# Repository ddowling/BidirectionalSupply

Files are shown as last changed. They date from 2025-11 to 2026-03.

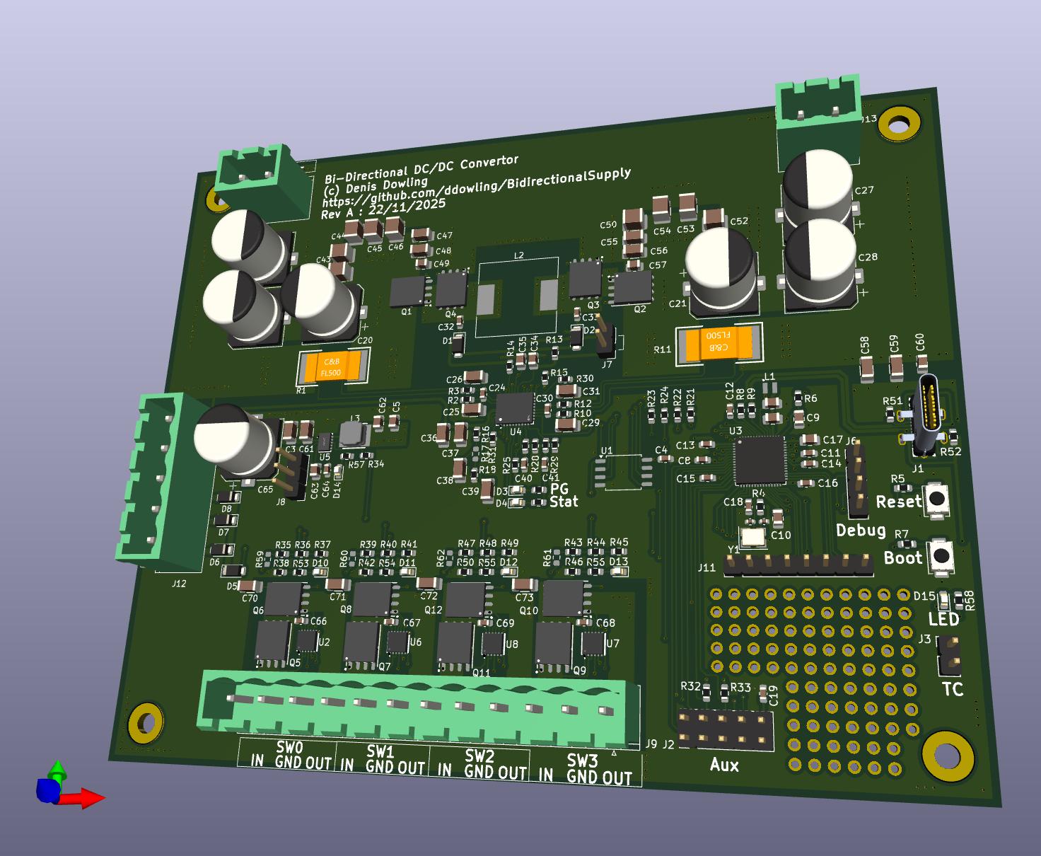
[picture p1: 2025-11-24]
doc/PCB3D.jpg

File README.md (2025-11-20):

This is a design for a Bidirectional Buck-Boost DC-DC converter based on the Texas Instruments [BQ25758](https://www.ti.com/lit/ds/symlink/bq25758.pdf) integrated circuit. 
The BQ25758 has a wide supply range from 4.2V to 60V and the external MOSFETs and Inductor should support currents up to 10A. This design is closely based on the 
[BQ25758 Evaluation Module](https://www.ti.com/lit/ug/sluucd0b/sluucd0b.pdf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). I decided to spin my own board as I
wanted to add a microcontroller and four Ideal Diodes with load switches to make a completely standalone board. 

I am interested in using this circuit as a DC UPS, Battery Charger and Solar MPPT. I have used various purpose build modules previously but I have often run into limitations due to their fixed 
function design and closed firmware.

The BQ25758 I<sub>2</sub>C interface is connected to an on-board RP2350 and there are 4 Ideal-Diode switches also connected to the RB2350. All of the high current connections are brought out to
pluggable terminal blocks so it is possible to reconfigure the circuit to accomodate different use cases. 
Having the ability to switch the DC-DC converter direction means that the system bus voltage can be decoupled from the battery voltage.

I was originally going to use a STM32 for the board microcontroller as I have used these on a lot of previous designed but when I started looking at battery capacity tracking algorithms I noted
that the more advanced employed an Unsented Kalman Filter and required the use of an Equivalent Circuit Model for the battery. I decided to opt for the
[RP2350](https://pip-assets.raspberrypi.com/categories/1214-rp2350/documents/RP-008373-DS-2-rp2350-datasheet.pdf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) with its hardware floating point and
the ability to run MicroPython as I figure this will be easier to iterate the firmware and run experiments on the board. Using MicroPython allow writing log files to the flash memory to
allow continous logging of battery voltage, current and temperature. This data can then be processed either on the board or remotely to allow a battery model to be fitted to actual
battery performance.

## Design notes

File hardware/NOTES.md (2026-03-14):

* I will be using JLCPCB for PCB, part sourcing and assembly.
* In the schematic symbol fields dialog I added an extra column for the JLCPCB part number. All of these parts should start with a "C".
* When the BOM is exported from KiCad it should be possible to import it directly into the JLCPCB BOM tool.
* Most of the footprints are obvious but things like the pushbutton switches are a specific layout. It is possible to convert from the JLCPCB part number to a footprint using the `easyeda2kicad` tool.

Install

    pip install easyeda2kicad

## BQ25758 IIN/IOUT Overcurrent Protection — Threshold Resistor Formula

The IIN and IOUT pins each have an internal transconductance amplifier that
converts the sense resistor voltage drop into a pin voltage used for OCP:

```
Vsense  = Isense × Rsense
Ipin    = Gm × Vsense
Vpin    = Ipin × Rpin        = Gm × Isense × Rsense × Rpin
Trip when Vpin ≥ Vthreshold  (Vthreshold = 2V, per datasheet)
```

Solving for the trip current limit:

```
Ilimit = Vthreshold / (Gm × Rsense × Rpin)
Rpin   = Vthreshold / (Gm × Rsense × Ilimit)
```

The IIN and IOUT pins have **different internal Gm values** (not documented in
the datasheet; determined by measurement). Both sense resistors are 5mR.

### IIN pin — Gm_in = 0.02 A/V (measured)

```
Ilimit = 2 / (0.02 × 5e-3 × Rpin) = 20000 / Rpin
Rpin   = 20000 / Ilimit
```

| Rpin | Ilimit |
|---|---|
| 4990 Ω | ~4.0 A  (original board build — too low for 10A operation) |
| 2000 Ω | 10.0 A  (target; use 2kΩ E24 standard value) |

**Action**: Replace the IIN pin resistor from 4990Ω to 2kΩ.

**Status (2026-03-14)**: Board #3 has been reworked with 2kΩ. Boards #1, #2, #4, #5
retain the original 4990Ω and will trip at ~4A in bypass mode — do not exceed
this when sweeping those boards until they are reworked.

### IOUT pin — Gm_out = 0.008 A/V (measured; = Gm_in × 2/5)

```
Ilimit = 2 / (0.008 × 5e-3 × Rpin) = 50000 / Rpin
Rpin   = 50000 / Ilimit
```

| Rpin | Ilimit |
|---|---|
| 4990 Ω | ~10.0 A (original board build — already correct for 10A) |
| 5000 Ω | 10.0 A  (nominal) |

**No change needed** to the IOUT pin resistor — 4990Ω gives ≈10A as intended.

### The 2/5 factor

The ratio Gm_out/Gm_in = 2/5 matches the same factor that causes the IIN ADC
to read at 0.8mA/LSB instead of the datasheet value of 2mA/LSB. Both effects
stem from the BQ25758's internal circuits behaving differently on the input
versus output path when the input sense resistor is 5mR rather than the 2mR
assumed by much of the datasheet text.

---

## Ideal Diode Switch (LM74810) — Negative Voltage Spike Issue

Board #1 had LM74810 ideal diode circuits destroyed, suspected to be caused by
negative voltage spikes on the switch input/output nodes exceeding the absolute
maximum ratings of the GATE and CATHODE pins.

Board #2 has 100nF capacitors added on the input and output of each ideal diode
switch circuit. This appears to suppress the spikes sufficiently — board #2 is
working correctly under switching tests. Confirmed by circuit inspection.

For the next PCB revision:
- Add 100nF caps on input and output of each ideal diode switch circuit
- Add bidirectional TVS on the input to each switch to clamp transients
  before they reach the LM74810

---

## Test Equipment — udev Rules

The IT8511 DC load is assigned a persistent alias via udev so scripts always
find it at `/dev/it8511` regardless of USB enumeration order.

Create `/etc/udev/rules.d/99-instruments.rules`:

```
SUBSYSTEM=="tty", ATTRS{idVendor}=="0403", ATTRS{idProduct}=="6001", ATTRS{serial}=="6676201034", SYMLINK+="it8511", GROUP="dialout"
```

Reload rules:
```bash
sudo udevadm control --reload-rules && sudo udevadm trigger
```

The Fluke 45 multimeter uses a Prolific PL2303 USB-serial adapter which has no
unique serial number, so matching by serial is not possible. Instead match on
the physical USB port path (KERNELS), which is stable as long as it is always
plugged into the same socket:

```
ACTION=="add", SUBSYSTEM=="tty", KERNELS=="<port_path>", SYMLINK+="fluke45", GROUP="dialout"
```

Find the port path with:
```bash
udevadm info -a -n /dev/ttyUSB0 | grep KERNELS | head -2
```

The RP2350 board enumerates as `/dev/ttyACM0` (no alias needed as only one
board is connected at a time).

---

## JLCPCB Fabrication

Grab footprint and 3d model

    easyeda2kicad  --footprint --3d --lcsc_id=C33222334
    easyeda2kicad --lcsc_id C559500 --symbol --footprint --3d --project-relative --output /mnt/hgfs/dpd/Documents/Open\ Source\ Solutions/BidirectionalSupply/hardware/BidirectionalSupply.kicad_sym

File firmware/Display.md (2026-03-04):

I have a couple of cheap 2.25" ST7789 RGB displays that I would like to use on this project. They are 284 x 76 pixel resolution.

https://www.ebay.com.au/itm/205521286472
https://www.aliexpress.com/item/1005008937314193.html

I found some good driver code from the repository at https://github.com/easytarget/st7789-framebuffer
It uses SPI to dump the full framebuffer to the display. This is most suitable in my application as I have enough RAM on the RP2350.

This repository recommends the microPyEZfonts repository for font handling
      https://github.com/easytarget/microPyEZfonts

I will clone this repository into the firmware directory and see if I can use something like symbolic links to just install the fonts required onto the device.

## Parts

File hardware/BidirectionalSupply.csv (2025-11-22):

Reference | Value | Footprint | Qty | DNP | JLCPCB | Mouser
C1,C2 | 15pF | BidirectionalSupply:C_0402_DRC | 2 |  | C1548
C3,C37,C47,C55,C58,C61 | 1uF/100VW | Capacitor_SMD:C_1206_3216Metric | 6 |  | C13832
C4,C8,C11,C12,C13,C14,C15,C16,C18,C19,C32,C33,C40,C41,C66,C67,C68,C69 | 100nF/25VW | Capacitor_SMD:C_0603_1608Metric | 18 |  | C1590
C5,C17,C62 | 10uF/25VW | Capacitor_SMD:C_0805_2012Metric | 3 |  | C15850
C6,C7,C9,C10,C34,C35,C63 | 4.7uF/25VW | Capacitor_SMD:C_0805_2012Metric | 7 |  | C1779
C20,C21,C22,C23,C27,C28,C65 | 56uF/80VW | Capacitor_SMD:CP_Elec_10x10.5 | 7 |  | C128515
C24,C30 | 470nF/16VW | Capacitor_SMD:C_0603_1608Metric | 2 |  | C1623
C25,C26,C29,C31,C36,C38,C39,C48,C56,C59,C70,C71,C72,C73 | 100nF/100VW | Capacitor_SMD:C_1206_3216Metric | 14 |  | C1945
C42,C43,C44,C50,C51,C52 | 10uF/100VW | Capacitor_SMD:C_1206_3216Metric | 6 |  | C5156756
C45,C46,C53,C54 | 4.7uF/100VW | Capacitor_SMD:C_1210_3225Metric | 4 |  | C385986
C49,C57 | 100pF/100VW | Capacitor_SMD:C_0805_2012Metric | 2 |  | C37456
C60 | 1nF/100VW | Capacitor_SMD:C_0805_2012Metric | 1 |  | C15177
C64 | 3.3nF | Capacitor_SMD:C_0603_1608Metric | 1 |  | C1613
D1,D2,D5,D6,D7,D8 | V1FM10-M3/H | Diode_SMD:D_SMF | 6 |  | C3758930
D3,D4,D10,D11,D12,D13,D14,D15 | RED | LED_SMD:LED_0603_1608Metric | 8 |  | C2286
J1 | USB-309GC-B-SU | BidirectionalSupply:USB-C-SMD_USB-309GC-B-SU | 1 |  | C309336
J2 | CON10 | Connector_PinHeader_2.54mm:PinHeader_2x05_P2.54mm_Vertical | 1
J3,J7 | CON2 | Connector_PinHeader_2.54mm:PinHeader_1x02_P2.54mm_Vertical | 2
J6 | CON4 | Connector_PinHeader_2.54mm:PinHeader_1x04_P2.54mm_Vertical | 1
J8 | Conn_01x03 | Connector_PinHeader_2.54mm:PinHeader_1x03_P2.54mm_Vertical | 1
J9 | Conn_01x12 | Connector_Phoenix_MSTB:PhoenixContact_MSTBVA_2,5_12-G-5,08_1x12_P5.08mm_Vertical | 1 |  |  | 651-1755833
J10,J13 | Conn_01x02 | Connector_Phoenix_MSTB:PhoenixContact_MSTBVA_2,5_2-G-5,08_1x02_P5.08mm_Vertical | 2
J11 | Conn_01x08 | Connector_PinHeader_2.54mm:PinHeader_1x08_P2.54mm_Vertical | 1
J12 | Conn_01x05 | Connector_Phoenix_MSTB:PhoenixContact_MSTBVA_2,5_5-G-5,08_1x05_P5.08mm_Vertical | 1
L1 | 3.3uH | BidirectionalSupply:L_pol_2016 | 1 |  | C42411119
L2 | 10uH | Inductor_SMD:L_Wuerth_HCM-1350 | 1 |  |  | 530-SCIHP1367-100M
L3 | 22uH | BidirectionalSupply:IND-SMD_L4.0-W4.0_SLW4010S | 1 |  | C83472
Q1,Q2,Q3,Q4,Q5,Q6,Q7,Q8,Q9,Q10,Q11,Q12 | SIR880BDP | BidirectionalSupply:POWERPAK-SO-8_L6.2-W5.2-P1.27-BL-EP | 12 |  | C5900133
R1,R11 | 5m | BidirectionalSupply:RES-SMD_L10.0-W5.2 | 2 |  | C481477
R2,R3,R10,R12 | 10R | Resistor_SMD:R_0603_1608Metric | 4 |  | C22859
R4,R5,R7,R19,R20,R53,R54,R55,R56,R57,R58 | 1k | Resistor_SMD:R_0603_1608Metric | 11 |  | C21190
R6 | 33R | Resistor_SMD:R_0603_1608Metric | 1 |  | C23140
R8,R9 | 27R | Resistor_SMD:R_0603_1608Metric | 2 |  | C25190
R13,R14,R15,R16,R18,R30,R34 | 0R | Resistor_SMD:R_0603_1608Metric | 7 |  | C21189
R21,R22,R23,R24,R25,R32,R33,R38,R42,R46,R50 | 10k | Resistor_SMD:R_0603_1608Metric | 11 |  | C25804
R26,R27 | 1k8 | Resistor_SMD:R_0603_1608Metric | 2 |  | C4177
R28,R29 | 4k99 | Resistor_SMD:R_0603_1608Metric | 2 |  | C2692815
R31 | 57k6 | Resistor_SMD:R_0603_1608Metric | 1 |  | C23082
R35,R39,R43,R47 | 97k6 | Resistor_SMD:R_0603_1608Metric | 4 |  | C2907079
R36,R40,R44,R48 | 3k1 | Resistor_SMD:R_0603_1608Metric | 4 |  | C2924132
R37,R41,R45,R49 | 2k1 | Resistor_SMD:R_0603_1608Metric | 4 |  | C22902
R51,R52 | 5k1 | Resistor_SMD:R_0603_1608Metric | 2 |  | C23186
SW1,SW2 | SW_Push | BidirectionalSupply:TS-1088-AR02016 | 2 |  | C720477
U1 | W25Q128JVS | Package_SO:SOIC-8_5.23x5.23mm_P1.27mm | 1 |  | C97521
U2,U6,U7,U8 | LM74810QDRRRQ1 | BidirectionalSupply:WSON-12_L3.0-W3.0-P0.50-TL-EP-2 | 4 |  | C3215601
U3 | RP2350_60QFN | BidirectionalSupply:RP2350-QFN-60-1EP_7x7_P0.4mm_EP3.4x3.4mm_ThermalVias | 1 |  | C42411118
U4 | BQ25758 | BidirectionalSupply:QFN-36_L6.0-W5.0-P0.50-BL-EP-1 | 1 |  | C33222334
U5 | MAX17502EATB+T | BidirectionalSupply:DFN-10_L3.0-W2.0-P0.50-BL-EP | 1 |  | C571005
Y1 | ABM8-272-T3 | BidirectionalSupply:Crystal_SMD_3225-4Pin_DRC | 1 |  | C20625731

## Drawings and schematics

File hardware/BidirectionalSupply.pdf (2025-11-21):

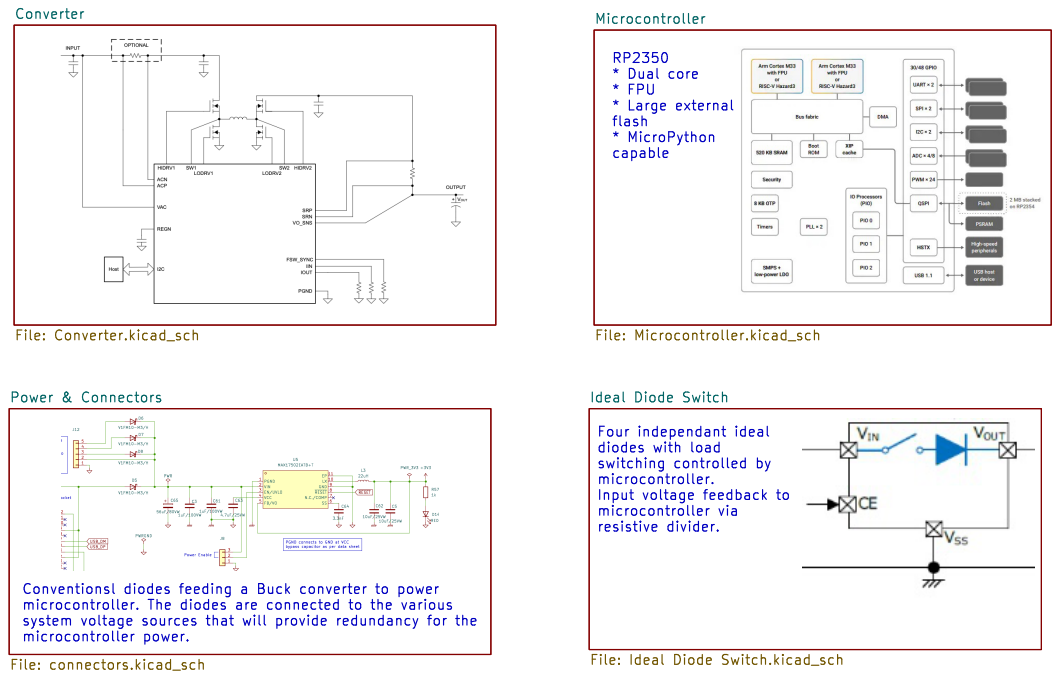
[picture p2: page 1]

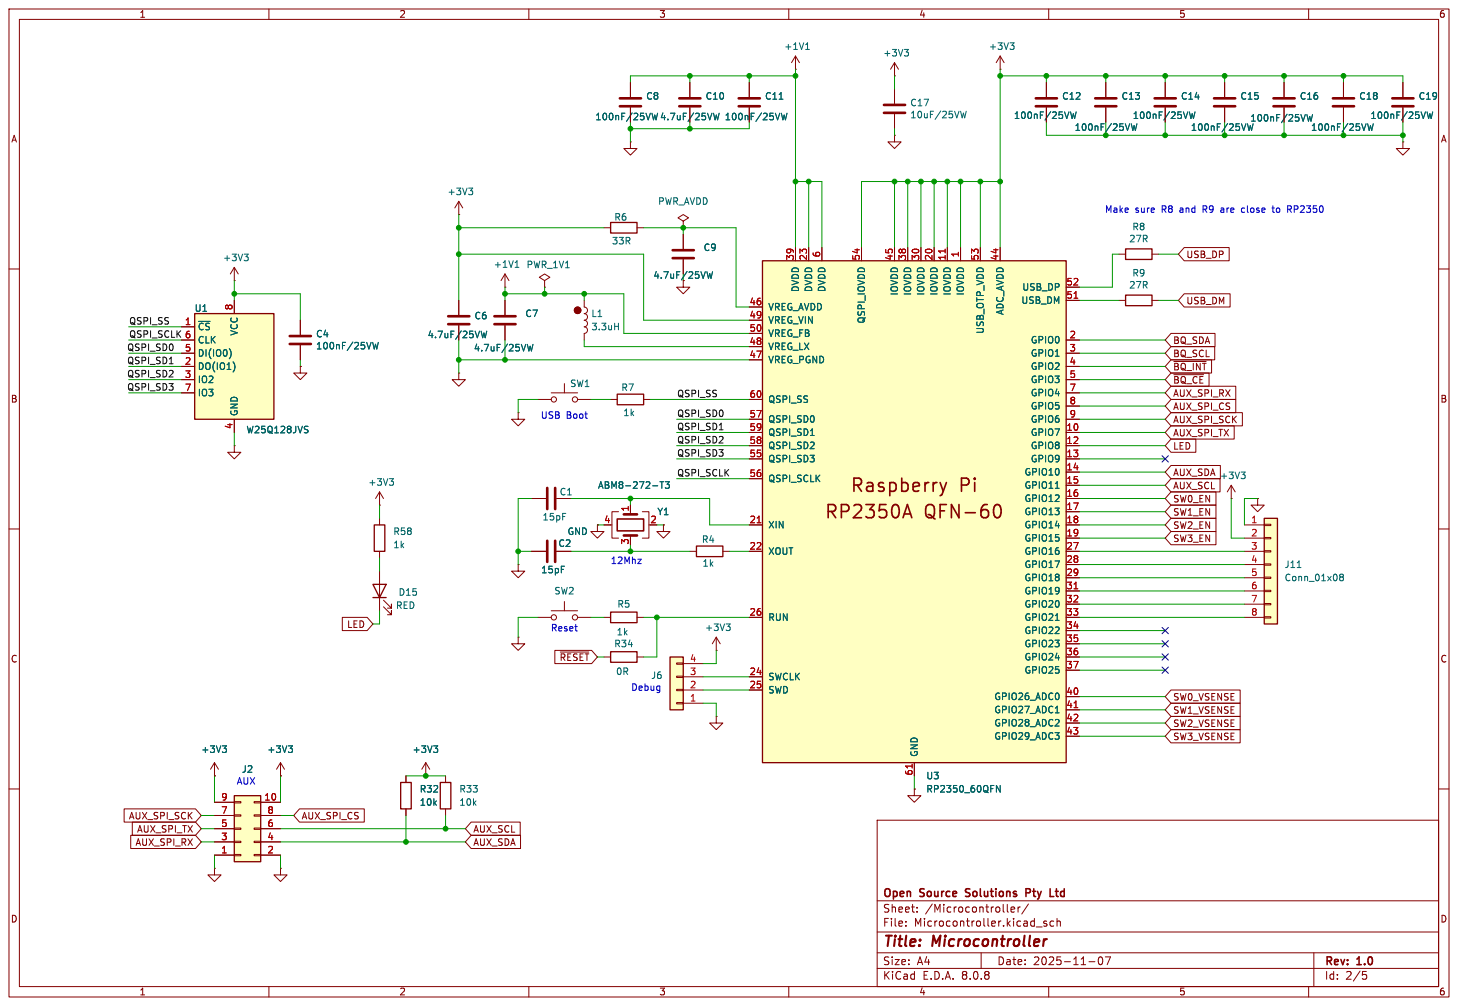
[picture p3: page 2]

1 GPIO7 10 IOVDD 11 GPIO8 12 GPIO9 13 GPIO10 14 GPIO11 15 GPIO12 16 GPIO13 17 GPIO14 18 GPIO15 19 GPIO0 2 IOVDD 20 XIN 21 XOUT 22 DVDD 23 SWCLK 24 SWD 25 RUN 26 GPIO16 27 GPIO17 28 GPIO18 29 GPIO1 3 IOVDD 30 GPIO19 31 GPIO20 32 GPIO21 33 GPIO22 34 GPIO23 35 GPIO24 36 GPIO25 37 IOVDD 38 DVDD 39 GPIO2 4 GPIO26_ADC0 40 GPIO27_ADC1 41 GPIO28_ADC2 42 GPIO29_ADC3 43 ADC_AVDD 44 IOVDD 45 VREG_AVDD 46 VREG_PGND 47 VREG_LX 48 VREG_VIN 49 GPIO3 5 VREG_FB 50 USB_DM 51 USB_DP 52 USB_OTP_VDD 53 QSPI_IOVDD 54 QSPI_SD3 55 QSPI_SCLK 56 QSPI_SD0 57 QSPI_SD2 58 QSPI_SD1 59 DVDD
U3 RP2350_60QFN IOVDD

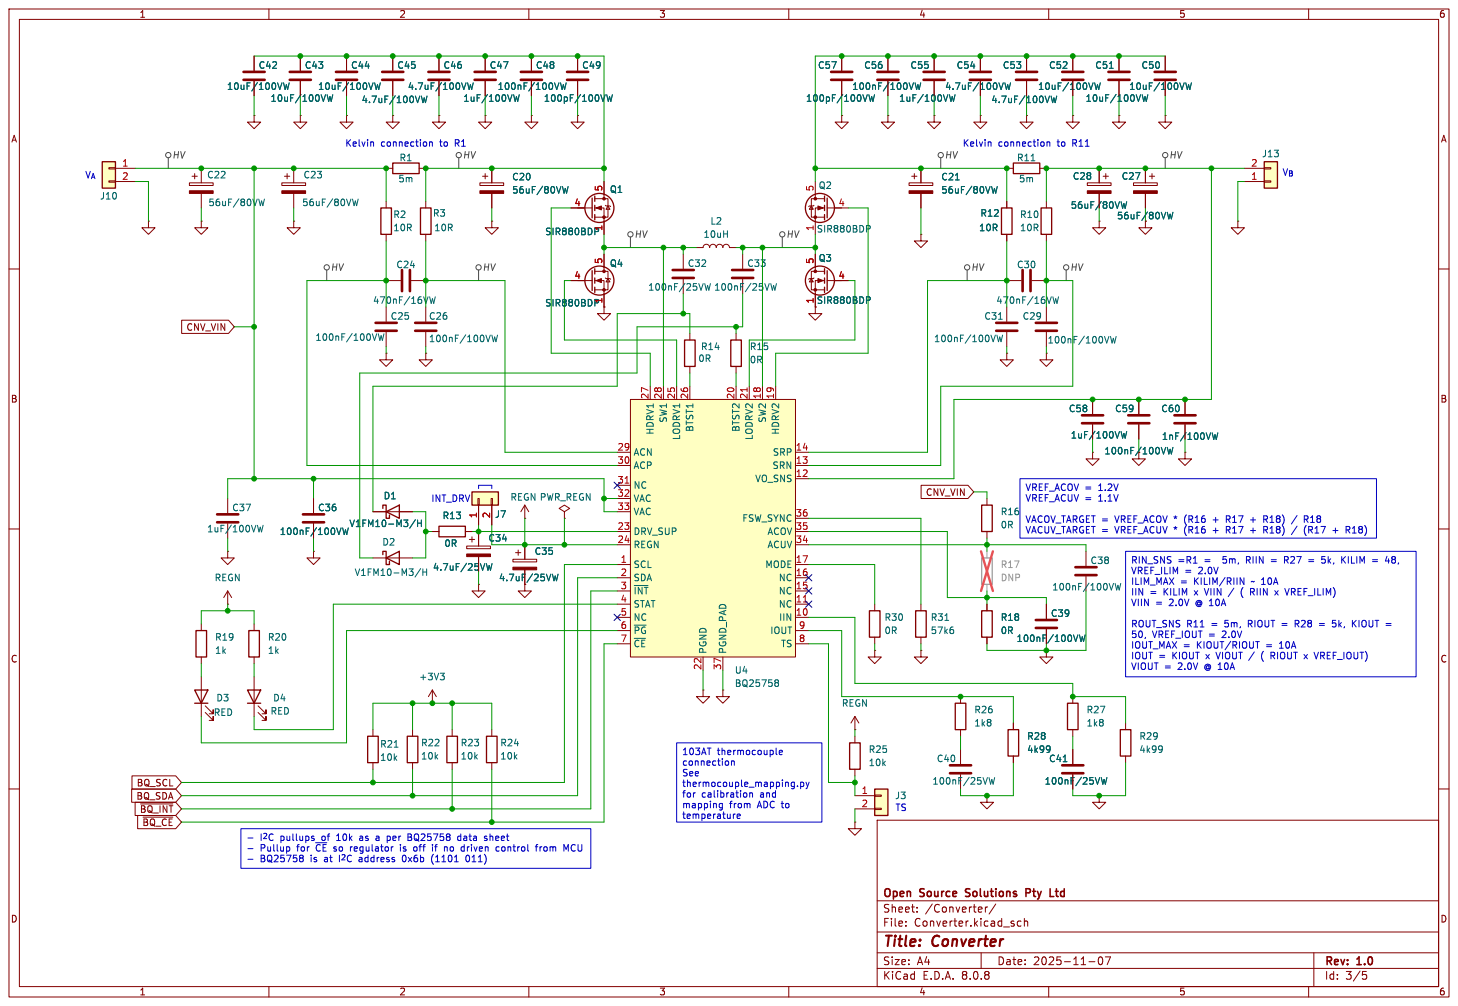
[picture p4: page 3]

IIN = KILIM x VIIN / ( RIIN x VREF_ILIM) VIIN = 2.0V @ 10A ROUT_SNS R11 = 5m, RIOUT = R28 = 5k, KIOUT =

50, VREF_IOUT = 2.0V
IOUT_MAX = KIOUT/RIOUT = 10A
IOUT = KIOUT x VIOUT / ( RIOUT x VREF_IOUT) VIOUT = 2.0V @ 10A

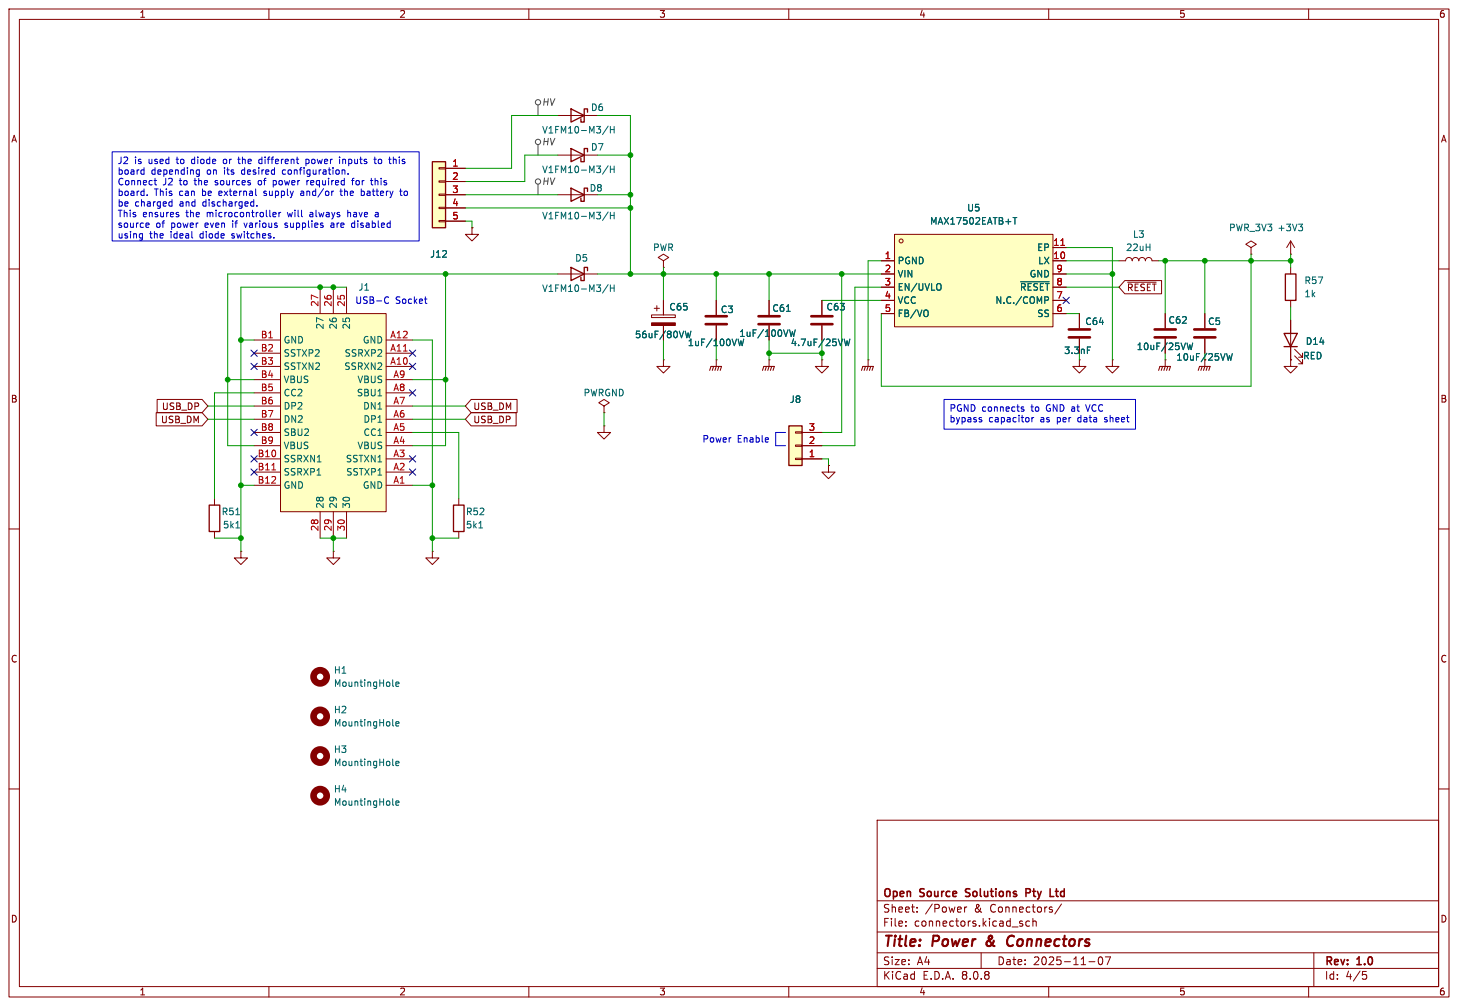
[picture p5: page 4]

Id: 4/5 Title: Power & Connectors

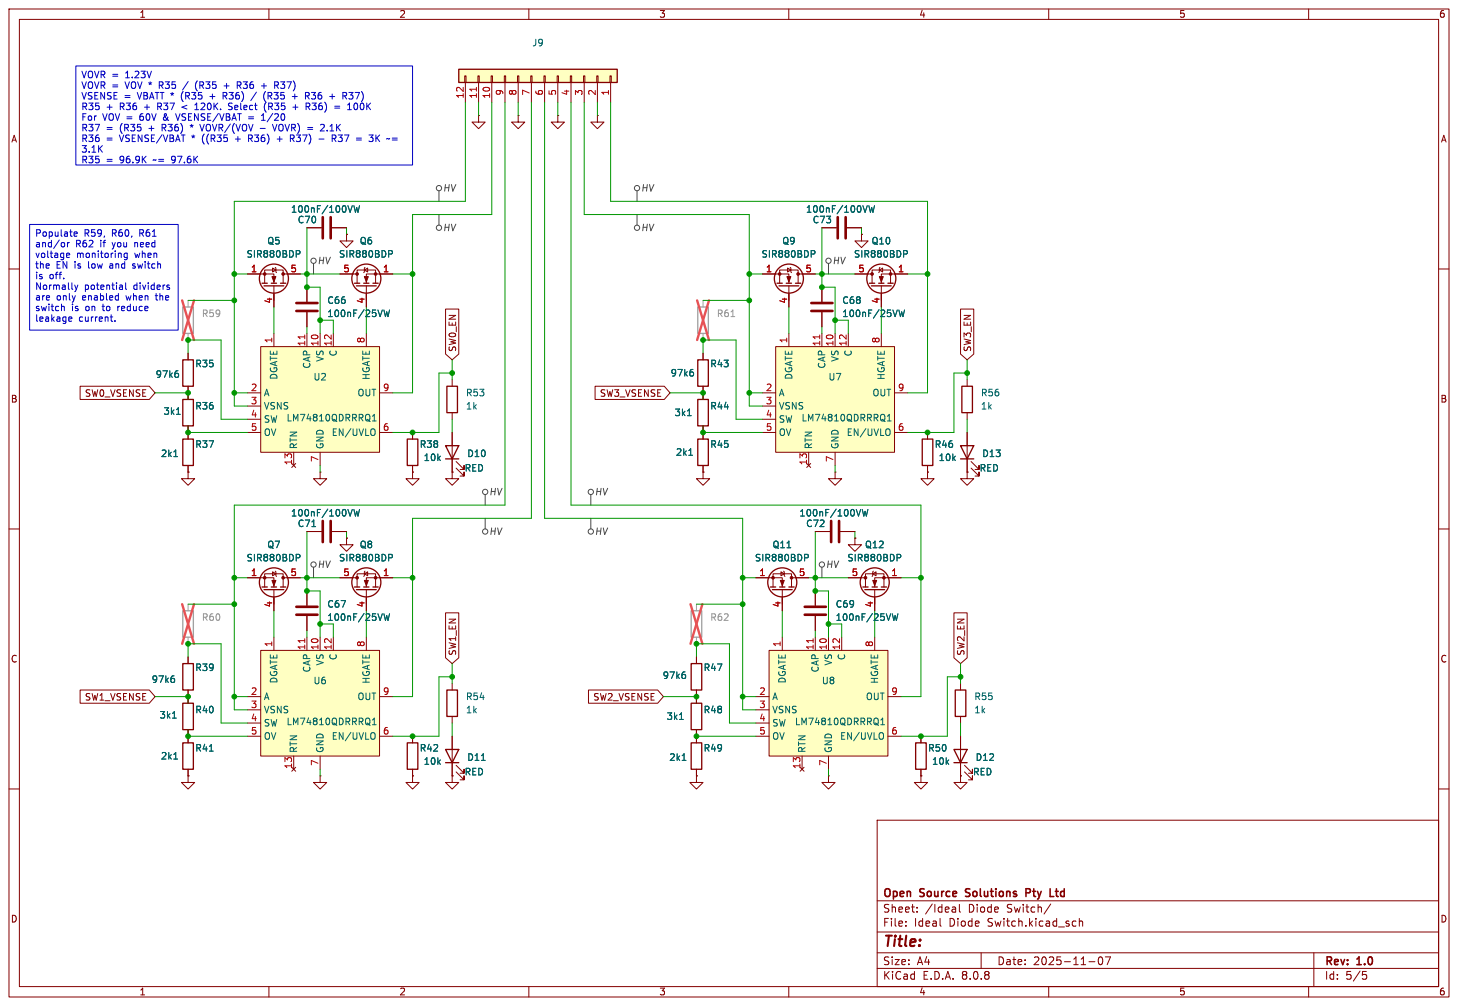
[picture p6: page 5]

VOVR = VOV * R35 / (R35 + R36 + R37) VSENSE = VBATT * (R35 + R36) / (R35 + R36 + R37) R35 + R36 + R37 < 120K. Select (R35 + R36) = 100K

For VOV = 60V & VSENSE/VBAT = 1/20 R37 = (R35 + R36) * VOVR/(VOV - VOVR) = 2.1K R36 = VSENSE/VBAT * ((R35 + R36) + R37) - R37 = 3K ~=

the EN is low and switch

switch is on to reduce

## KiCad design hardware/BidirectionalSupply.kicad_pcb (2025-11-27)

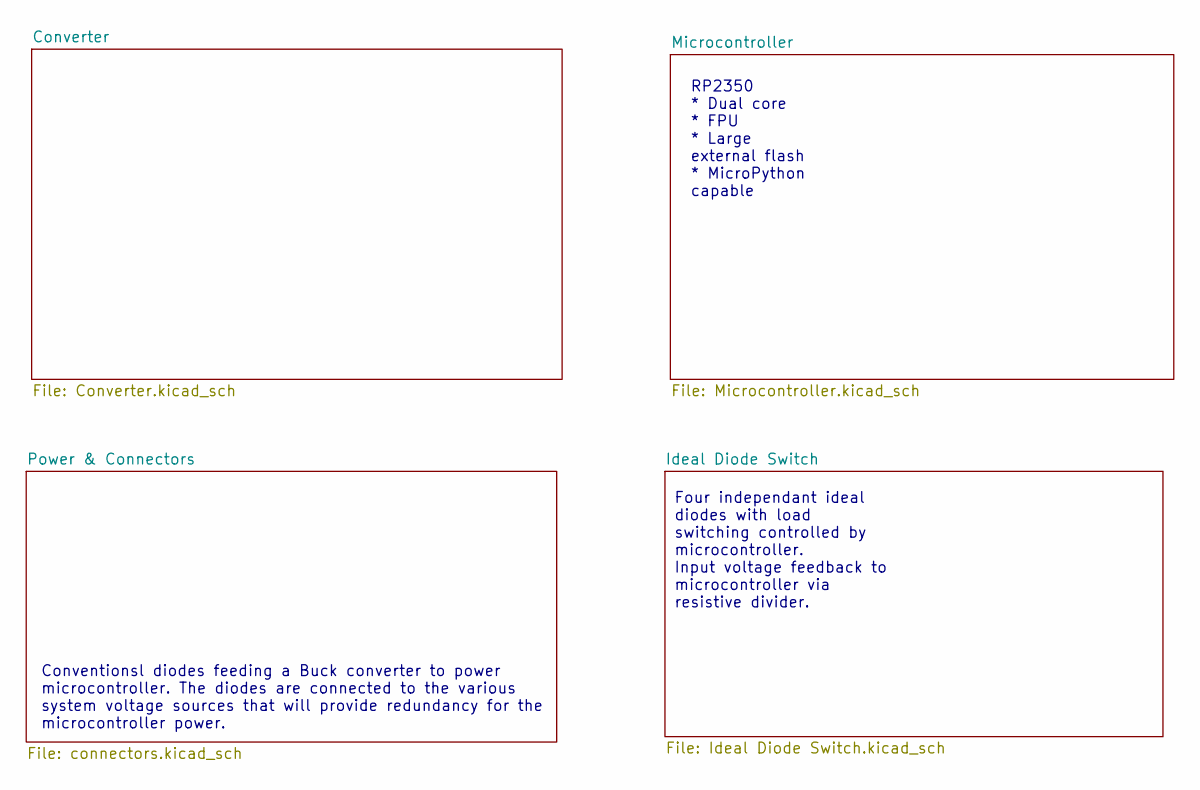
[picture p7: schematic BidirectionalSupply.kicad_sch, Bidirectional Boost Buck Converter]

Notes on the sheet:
RP2350 * Dual core * FPU * Large external flash * MicroPython capable
Four independant ideal diodes with load switching controlled by microcontroller. Input voltage feedback to microcontroller via resistive divider.
Conventionsl diodes feeding a Buck converter to power microcontroller. The diodes are connected to the various system voltage sources that will provide redundancy for the microcontroller power.

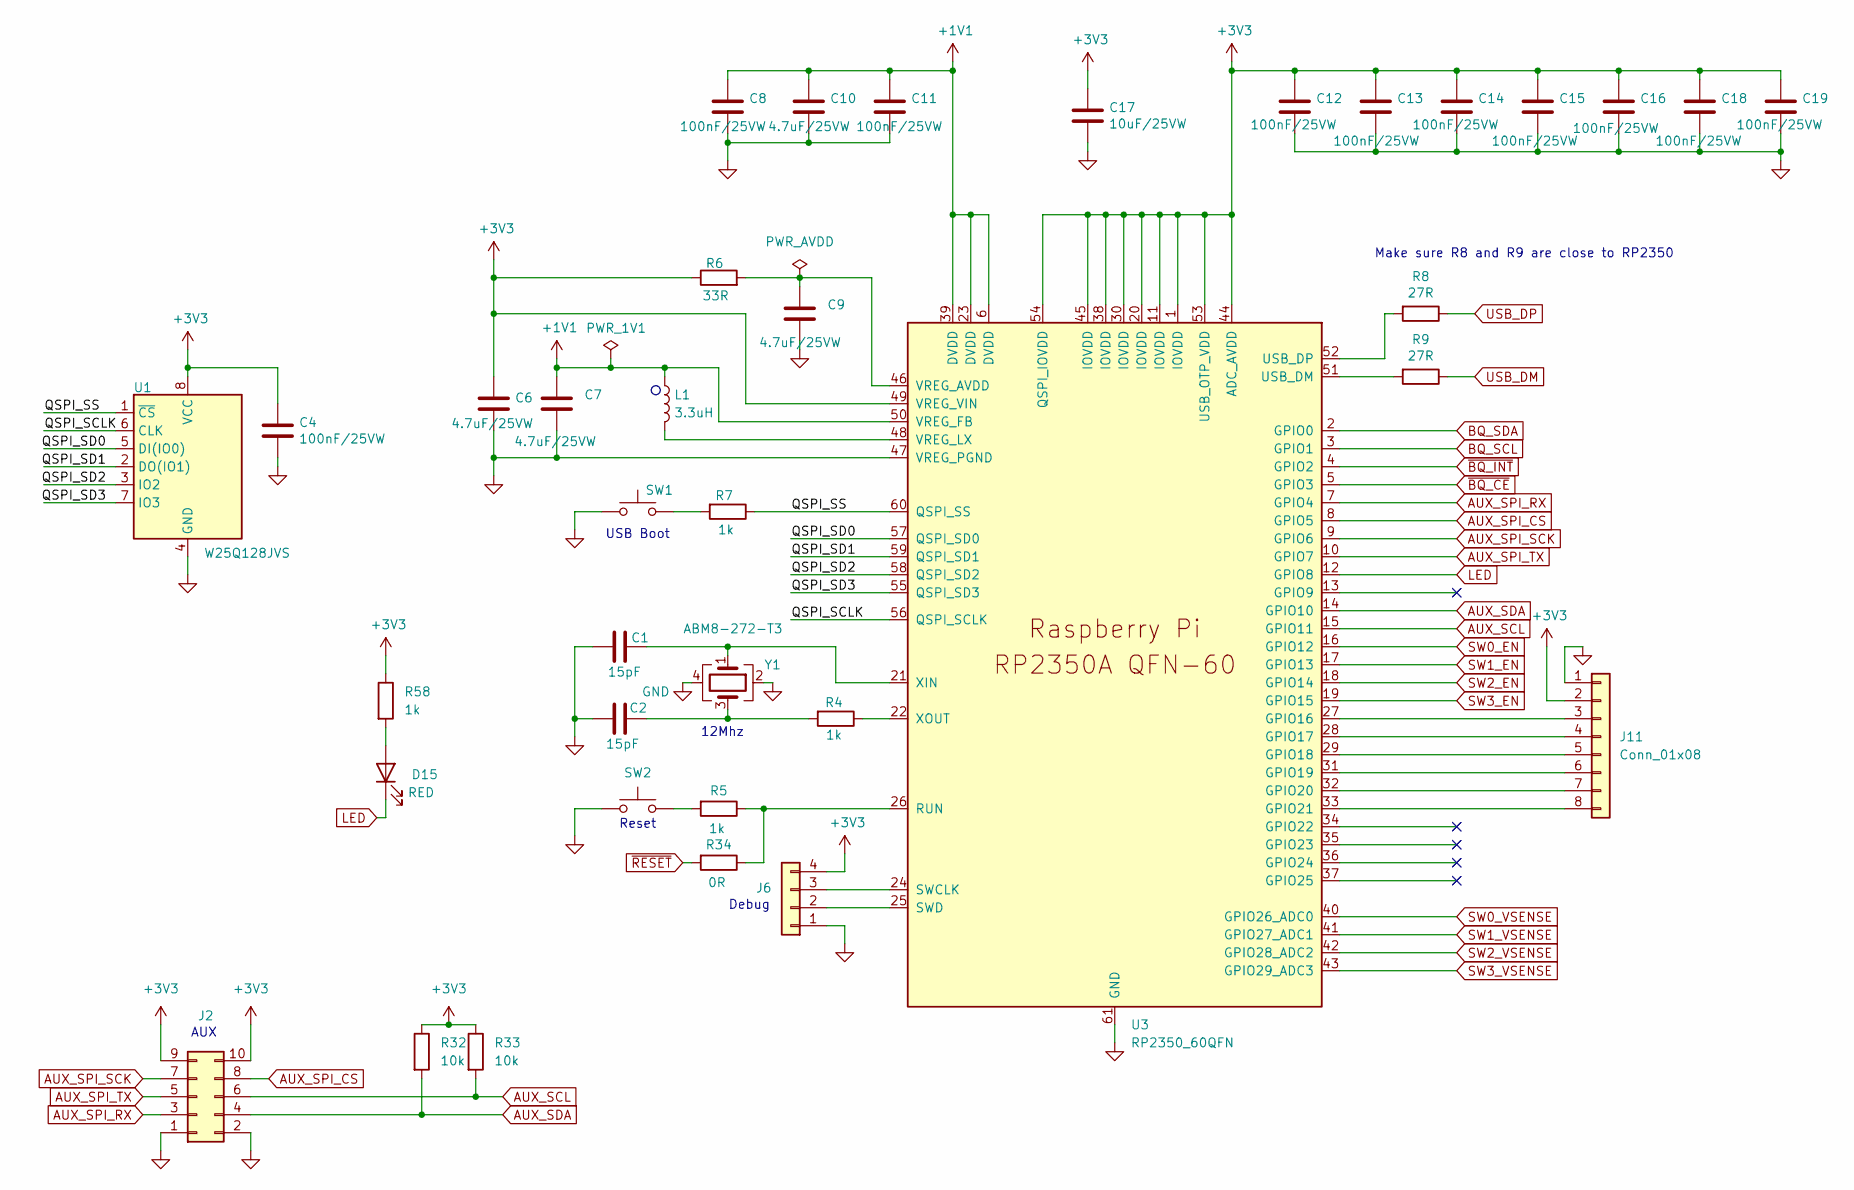
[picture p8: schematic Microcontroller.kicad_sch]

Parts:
C1, C2: 15pF; C_0402_DRC; JLCPCB C1548
C4, C8, C11, C12, C13, C14, C15, C16, C18, C19: 100nF/25VW; C_0603_1608Metric; JLCPCB C1590
C6, C7, C9, C10: 4.7uF/25VW; C_0805_2012Metric; JLCPCB C1779
C17: 10uF/25VW; C_0805_2012Metric; JLCPCB C15850
D15: RED; LED_0603_1608Metric; JLCPCB C2286
J2: CON10; PinHeader_2x05_P2.54mm_Vertical
J6: CON4; PinHeader_1x04_P2.54mm_Vertical
J11: Conn_01x08; PinHeader_1x08_P2.54mm_Vertical
L1: 3.3uH; L_pol_2016; JLCPCB C42411119
R4, R5, R7, R58: 1k; R_0603_1608Metric; JLCPCB C21190
R6: 33R; R_0603_1608Metric; JLCPCB C23140
R8, R9: 27R; R_0603_1608Metric; JLCPCB C25190
R32, R33: 10k; R_0603_1608Metric; JLCPCB C25804
R34: 0R; R_0603_1608Metric; JLCPCB C21189
SW1, SW2: SW_Push; TS-1088-AR02016; JLCPCB C720477
U1: W25Q128JVS; SOIC-8_5.23x5.23mm_P1.27mm; JLCPCB C97521
U3: RP2350_60QFN; RP2350-QFN-60-1EP_7x7_P0.4mm_EP3.4x3.4mm_ThermalVias; JLCPCB C42411118
Y1: ABM8-272-T3; Crystal_SMD_3225-4Pin_DRC; JLCPCB C20625731

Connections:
+1V1: C7.1, C8.1, C10.1, C11.1, L1.1, U3.6 (DVDD), U3.23 (DVDD), U3.39 (DVDD), U3.50 (VREG_FB)
+3V3: C4.1, C6.1, C12.1, C13.1, C14.1, C15.1, C16.1, C17.1, C18.1, C19.1, J2.9, J2.10, J6.4, J11.2, R6.1, R32.1, R33.1, R58.1, U1.8 (VCC), U3.1 (IOVDD), U3.11 (IOVDD), U3.20 (IOVDD), U3.30 (IOVDD), U3.38 (IOVDD), U3.44 (ADC_AVDD), U3.45 (IOVDD), U3.49 (VREG_VIN), U3.53 (USB_OTP_VDD), U3.54 (QSPI_IOVDD); also elsewhere on the board
/Microcontroller/QSPI_SCLK: U1.6 (CLK), U3.56 (QSPI_SCLK)
/Microcontroller/QSPI_SD0: U1.5 (DI(IO0)), U3.57 (QSPI_SD0)
/Microcontroller/QSPI_SD1: U1.2 (DO(IO1)), U3.59 (QSPI_SD1)
/Microcontroller/QSPI_SD2: U1.3 (IO2), U3.58 (QSPI_SD2)
/Microcontroller/QSPI_SD3: U1.7 (IO3), U3.55 (QSPI_SD3)
/Microcontroller/QSPI_SS: R7.1, U1.1 (~CS), U3.60 (QSPI_SS)
AUX_SCL: J2.6, R33.2, U3.15 (GPIO11)
AUX_SDA: J2.4, R32.2, U3.14 (GPIO10)
AUX_SPI_CS: J2.8, U3.8 (GPIO5)
AUX_SPI_RX: J2.3, U3.7 (GPIO4)
AUX_SPI_SCK: J2.7, U3.9 (GPIO6)
AUX_SPI_TX: J2.5, U3.10 (GPIO7)
BQ_SCL: U3.3 (GPIO1); also elsewhere on the board
BQ_SDA: U3.2 (GPIO0); also elsewhere on the board
GND: C1.2, C2.2, C4.2, C6.2, C7.2, C8.2, C9.2, C10.2, C11.2, C12.2, C13.2, C14.2, C15.2, C16.2, C17.2, C18.2, C19.2, J2.1, J2.2, J6.1, J11.1, SW1.1, SW2.1, U1.4 (GND), U3.47 (VREG_PGND), U3.61 (GND), Y1.2, Y1.4; also elsewhere on the board
LED: D15.1 (K), U3.12 (GPIO8)
unnamed: C2.1, R4.2, Y1.3
unnamed: D15.2 (A), R58.2
unnamed: J6.2, U3.25 (SWD)
unnamed: J6.3, U3.24 (SWCLK)
unnamed: J11.3, U3.27 (GPIO16)
unnamed: J11.4, U3.28 (GPIO17)
unnamed: J11.5, U3.29 (GPIO18)
unnamed: J11.6, U3.31 (GPIO19)
unnamed: J11.7, U3.32 (GPIO20)
unnamed: J11.8, U3.33 (GPIO21)
unnamed: R5.2, SW2.2
unnamed: R7.2, SW1.2
unnamed: R5.1, R34.1, U3.26 (RUN)
unnamed: R9.2, U3.51 (USB_DM)
unnamed: R8.2, U3.52 (USB_DP)
unnamed: C9.1, R6.2, U3.46 (VREG_AVDD)
unnamed: L1.2, U3.48 (VREG_LX)
unnamed: C1.1, U3.21 (XIN), Y1.1
unnamed: R4.1, U3.22 (XOUT)
SW0_EN: U3.16 (GPIO12); also elsewhere on the board
SW0_VSENSE: U3.40 (GPIO26_ADC0); also elsewhere on the board
SW1_EN: U3.17 (GPIO13); also elsewhere on the board
SW1_VSENSE: U3.41 (GPIO27_ADC1); also elsewhere on the board
SW2_EN: U3.18 (GPIO14); also elsewhere on the board
SW2_VSENSE: U3.42 (GPIO28_ADC2); also elsewhere on the board
SW3_EN: U3.19 (GPIO15); also elsewhere on the board
SW3_VSENSE: U3.43 (GPIO29_ADC3); also elsewhere on the board
USB_DM: R9.1; also elsewhere on the board
USB_DP: R8.1; also elsewhere on the board
~BQ_CE: U3.5 (GPIO3); also elsewhere on the board
~BQ_INT: U3.4 (GPIO2); also elsewhere on the board
~RESET: R34.2; also elsewhere on the board

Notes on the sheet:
Debug
Make sure R8 and R9 are close to RP2350
USB Boot
AUX
Reset
12Mhz

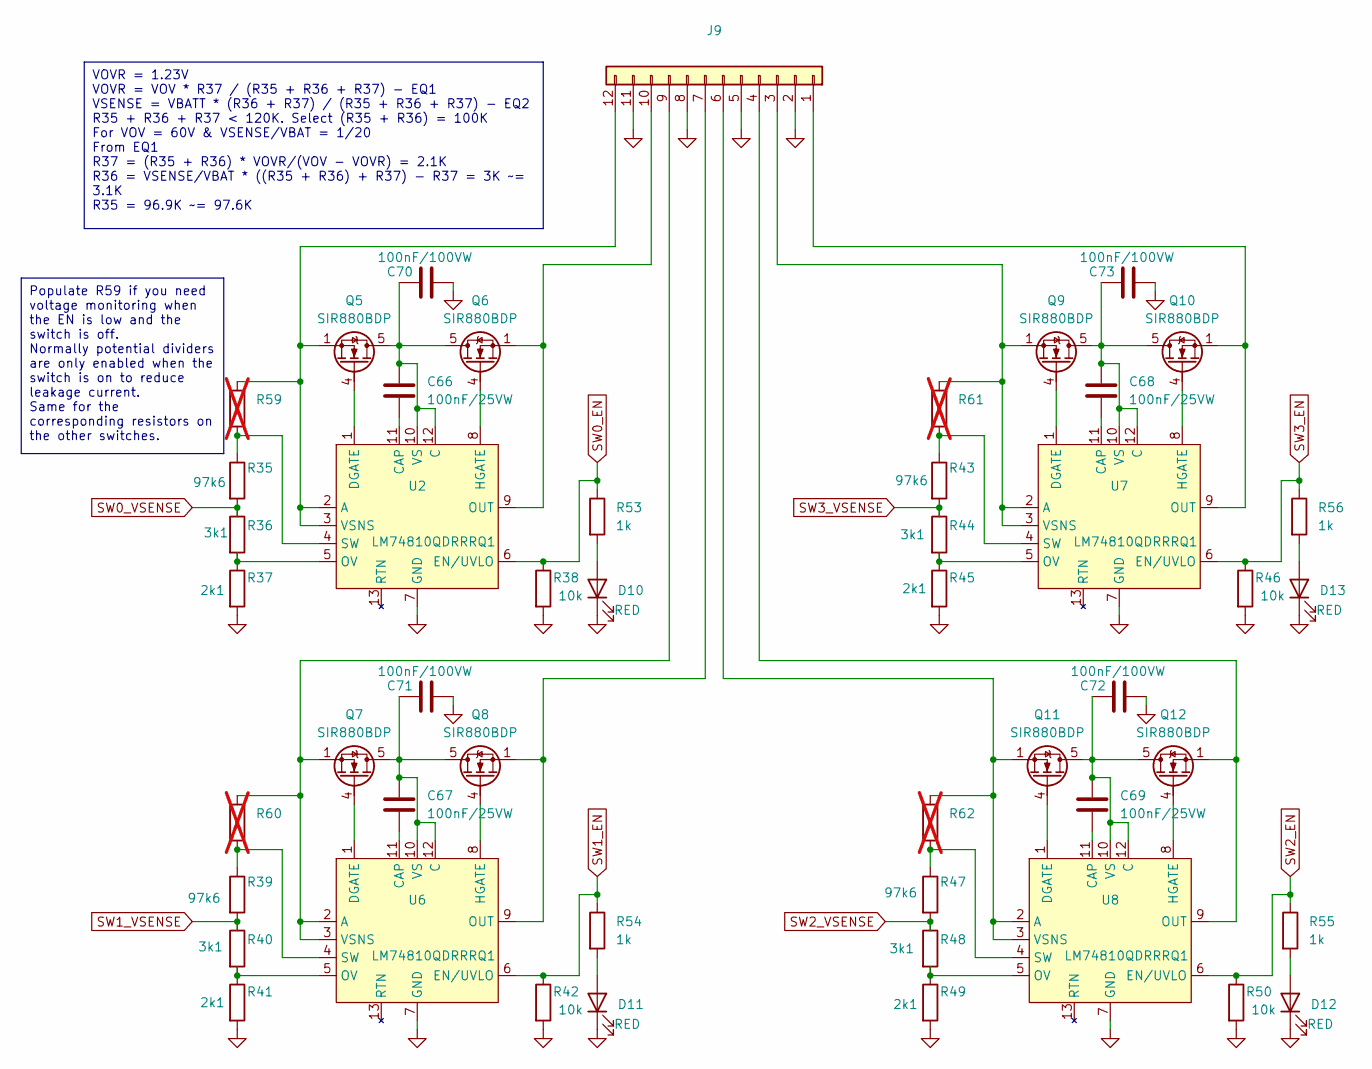
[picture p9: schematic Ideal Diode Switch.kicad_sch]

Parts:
C66, C67, C68, C69: 100nF/25VW; C_0603_1608Metric; JLCPCB C1590
C70, C71, C72, C73: 100nF/100VW; C_1206_3216Metric; JLCPCB C1945
D10, D11, D12, D13: RED; LED_0603_1608Metric; JLCPCB C2286
J9: Conn_01x12; PhoenixContact_MSTBVA_2,5_12-G-5,08_1x12_P5.08mm_Vertical; Mouser 651-1755833
Q5, Q6, Q7, Q8, Q9, Q10, Q11, Q12: SIR880BDP; POWERPAK-SO-8_L6.2-W5.2-P1.27-BL-EP; LCSC Part C5900133
R35, R39, R43, R47: 97k6; R_0603_1608Metric; JLCPCB C2907079
R36, R40, R44, R48: 3k1; R_0603_1608Metric; JLCPCB C2924132
R37, R41, R45, R49: 2k1; R_0603_1608Metric; JLCPCB C22902
R38, R42, R46, R50: 10k; R_0603_1608Metric; JLCPCB C25804
R53, R54, R55, R56: 1k; R_0603_1608Metric; JLCPCB C21190
R59, R60, R61, R62: 0R; R_0603_1608Metric; not fitted
U2, U6, U7, U8: LM74810QDRRRQ1; WSON-12_L3.0-W3.0-P0.50-TL-EP-2; LCSC Part C3215601

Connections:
GND: C70.2, C71.2, C72.2, C73.2, D10.1 (K), D11.1 (K), D12.1 (K), D13.1 (K), J9.2, J9.5, J9.8, J9.11, R37.2, R38.2, R41.2, R42.2, R45.2, R46.2, R49.2, R50.2, U2.7 (GND), U6.7 (GND), U7.7 (GND), U8.7 (GND); also elsewhere on the board
unnamed: D10.2 (A), R53.2
unnamed: D11.2 (A), R54.2
unnamed: D12.2 (A), R55.2
unnamed: D13.2 (A), R56.2
unnamed: J9.1, Q10.1 (S), Q10.2 (S), Q10.3 (S), U7.9 (OUT)
unnamed: J9.3, Q9.1 (S), Q9.2 (S), Q9.3 (S), R61.1, U7.2 (A), U7.3 (VSNS)
unnamed: J9.4, Q12.1 (S), Q12.2 (S), Q12.3 (S), U8.9 (OUT)
unnamed: J9.6, Q11.1 (S), Q11.2 (S), Q11.3 (S), R62.1, U8.2 (A), U8.3 (VSNS)
unnamed: J9.7, Q8.1 (S), Q8.2 (S), Q8.3 (S), U6.9 (OUT)
unnamed: J9.9, Q7.1 (S), Q7.2 (S), Q7.3 (S), R60.1, U6.2 (A), U6.3 (VSNS)
unnamed: J9.10, Q6.1 (S), Q6.2 (S), Q6.3 (S), U2.9 (OUT)
unnamed: J9.12, Q5.1 (S), Q5.2 (S), Q5.3 (S), R59.1, U2.2 (A), U2.3 (VSNS)
unnamed: C66.1, C70.1, Q5.5 (D), Q5.6 (D), Q5.7 (D), Q5.8 (D), Q5.9 (EP), Q6.5 (D), Q6.6 (D), Q6.7 (D), Q6.8 (D), Q6.9 (EP), U2.10 (VS), U2.12 (C)
unnamed: Q5.4 (G), U2.1 (DGATE)
unnamed: Q6.4 (G), U2.8 (HGATE)
unnamed: C67.1, C71.1, Q7.5 (D), Q7.6 (D), Q7.7 (D), Q7.8 (D), Q7.9 (EP), Q8.5 (D), Q8.6 (D), Q8.7 (D), Q8.8 (D), Q8.9 (EP), U6.10 (VS), U6.12 (C)
unnamed: Q7.4 (G), U6.1 (DGATE)
unnamed: Q8.4 (G), U6.8 (HGATE)
unnamed: Q9.4 (G), U7.1 (DGATE)
unnamed: C68.1, C73.1, Q9.5 (D), Q9.6 (D), Q9.7 (D), Q9.8 (D), Q9.9 (EP), Q10.5 (D), Q10.6 (D), Q10.7 (D), Q10.8 (D), Q10.9 (EP), U7.10 (VS), U7.12 (C)
unnamed: Q10.4 (G), U7.8 (HGATE)
unnamed: C69.1, C72.1, Q11.5 (D), Q11.6 (D), Q11.7 (D), Q11.8 (D), Q11.9 (EP), Q12.5 (D), Q12.6 (D), Q12.7 (D), Q12.8 (D), Q12.9 (EP), U8.10 (VS), U8.12 (C)
unnamed: Q11.4 (G), U8.1 (DGATE)
unnamed: Q12.4 (G), U8.8 (HGATE)
unnamed: C66.2, U2.11 (CAP)
unnamed: R36.2, R37.1, U2.5 (OV)
unnamed: R35.1, R59.2, U2.4 (SW)
unnamed: C67.2, U6.11 (CAP)
unnamed: R40.2, R41.1, U6.5 (OV)
unnamed: R39.1, R60.2, U6.4 (SW)
unnamed: C68.2, U7.11 (CAP)
unnamed: R44.2, R45.1, U7.5 (OV)
unnamed: R43.1, R61.2, U7.4 (SW)
unnamed: C69.2, U8.11 (CAP)
unnamed: R48.2, R49.1, U8.5 (OV)
unnamed: R47.1, R62.2, U8.4 (SW)
SW0_EN: R38.1, R53.1, U2.6 (EN/UVLO); also elsewhere on the board
SW0_VSENSE: R35.2, R36.1; also elsewhere on the board
SW1_EN: R42.1, R54.1, U6.6 (EN/UVLO); also elsewhere on the board
SW1_VSENSE: R39.2, R40.1; also elsewhere on the board
SW2_EN: R50.1, R55.1, U8.6 (EN/UVLO); also elsewhere on the board
SW2_VSENSE: R47.2, R48.1; also elsewhere on the board
SW3_EN: R46.1, R56.1, U7.6 (EN/UVLO); also elsewhere on the board
SW3_VSENSE: R43.2, R44.1; also elsewhere on the board

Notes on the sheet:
VOVR = 1.23V VOVR = VOV * R37 / (R35 + R36 + R37) - EQ1 VSENSE = VBATT * (R36 + R37) / (R35 + R36 + R37) - EQ2 R35 + R36 + R37 < 120K. Select (R35 + R36) = 100K For VOV = 60V & VSENSE/VBAT = 1/20 From EQ1 R37 = (R35 + R36) * VOVR/(VOV - VOVR) = 2.1K R36 = VSENSE/VBAT * ((R35 + R36) + R37) - R37 = 3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
Populate R59 if you need voltage monitoring when the EN is low and the switch is off. Normally potential dividers are only enabled when the switch is on to reduce leakage current. Same for the corresponding resistors on the other switches.

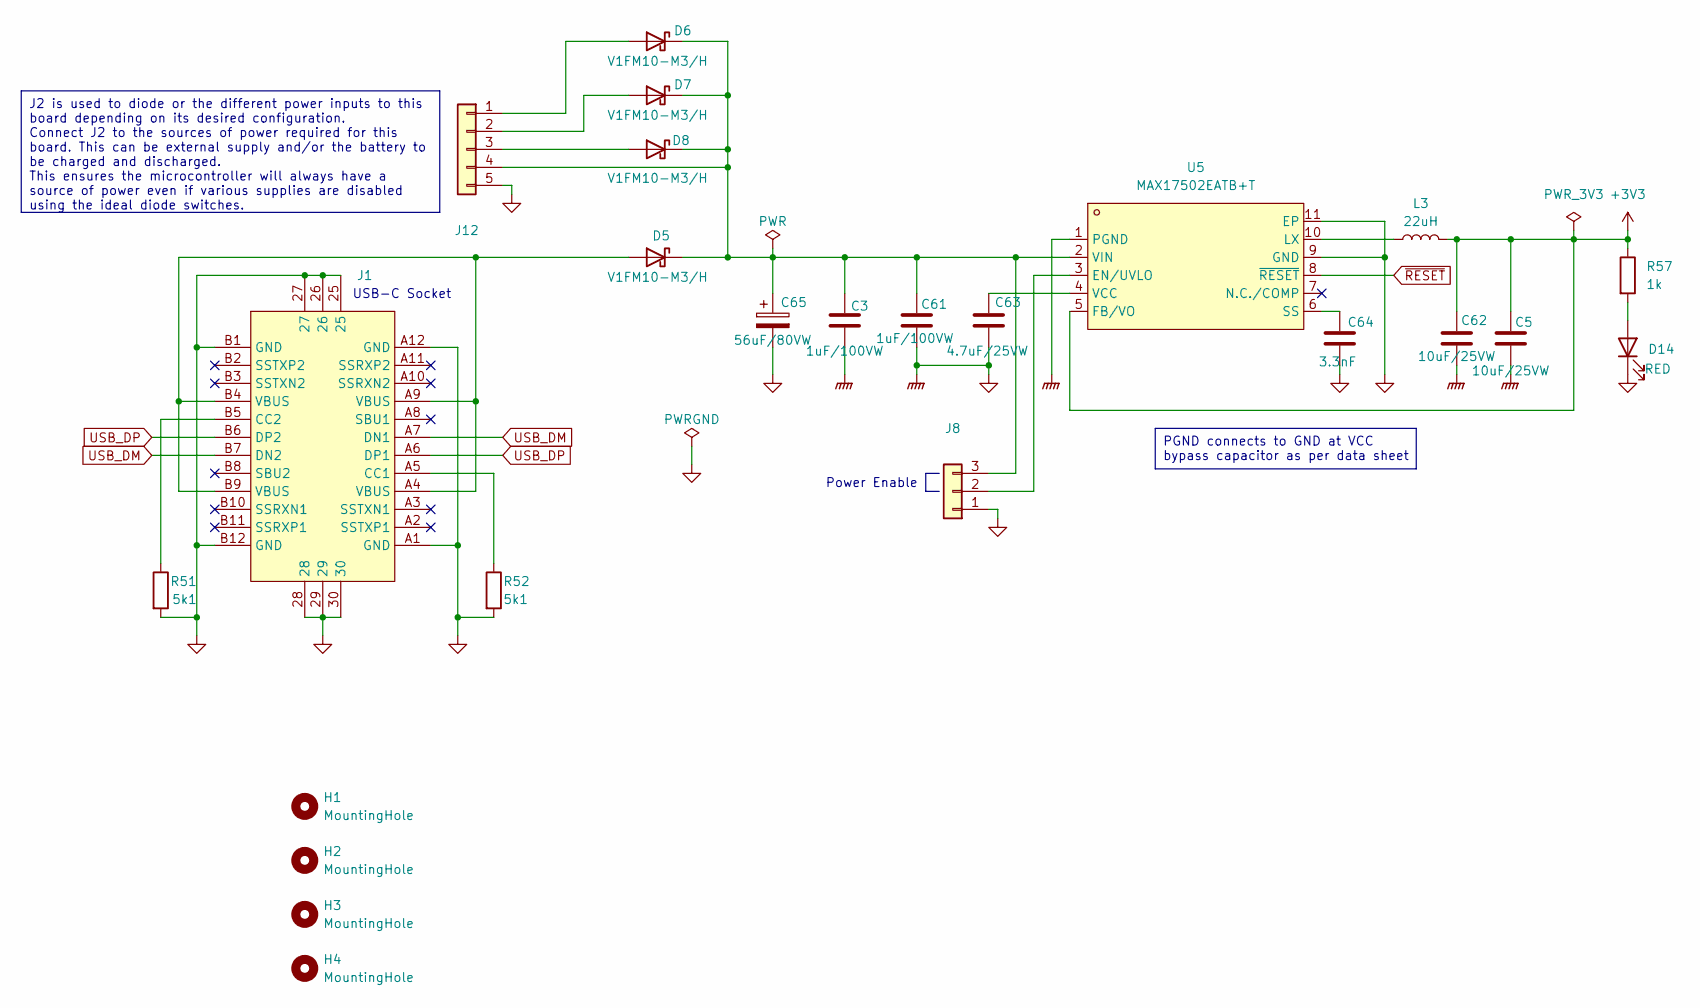
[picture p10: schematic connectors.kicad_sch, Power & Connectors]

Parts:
C3, C61: 1uF/100VW; C_1206_3216Metric; JLCPCB C13832
C5, C62: 10uF/25VW; C_0805_2012Metric; JLCPCB C15850
C63: 4.7uF/25VW; C_0805_2012Metric; JLCPCB C1779
C64: 3.3nF; C_0603_1608Metric; JLCPCB C1613
C65: 56uF/80VW; CP_Elec_10x10.5; JLCPCB C128515
D5, D6, D7, D8: V1FM10-M3/H; D_SMF; JLCPCB C3758930
D14: RED; LED_0603_1608Metric; JLCPCB C2286
H1, H2, H3, H4: MountingHole; MountingHole_3.2mm_M3_Pad
J1: USB-309GC-B-SU; USB-C-SMD_USB-309GC-B-SU; LCSC Part C309336
J8: Conn_01x03; PinHeader_1x03_P2.54mm_Vertical
J12: Conn_01x05; PhoenixContact_MSTBVA_2,5_5-G-5,08_1x05_P5.08mm_Vertical
L3: 22uH; IND-SMD_L4.0-W4.0_SLW4010S; JLCPCB C83472
R51, R52: 5k1; R_0603_1608Metric; JLCPCB C23186
R57: 1k; R_0603_1608Metric; JLCPCB C21190
U5: MAX17502EATB+T; DFN-10_L3.0-W2.0-P0.50-BL-EP; LCSC Part C571005

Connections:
+3V3: C5.1, C62.1, L3.2, R57.1, U5.5 (FB/VO); also elsewhere on the board
GND: C3.2, C5.2, C61.2, C62.2, C63.2, C64.2, C65.2, D14.1 (K), J1.25, J1.26, J1.27, J1.28, J1.29, J1.30, J1.A1 (GND), J1.A12 (GND), J1.B1 (GND), J1.B12 (GND), J8.1, J12.5, R51.2, R52.2, U5.1 (PGND), U5.9 (GND), U5.11 (EP); also elsewhere on the board
unnamed: D5.2 (A), J1.A4 (VBUS), J1.A9 (VBUS), J1.B4 (VBUS), J1.B9 (VBUS)
unnamed: C3.1, C61.1, C65.1, D5.1 (K), D6.1 (K), D7.1 (K), D8.1 (K), J8.3, J12.4, U5.2 (VIN)
unnamed: D6.2 (A), J12.1
unnamed: D7.2 (A), J12.2
unnamed: D8.2 (A), J12.3
unnamed: D14.2 (A), R57.2
unnamed: J1.A5 (CC1), R52.1
unnamed: J1.B5 (CC2), R51.1
unnamed: J8.2, U5.3 (EN/UVLO)
unnamed: L3.1, U5.10 (LX)
unnamed: C64.1, U5.6 (SS)
unnamed: C63.1, U5.4 (VCC)
USB_DM: J1.A7 (DN1), J1.B7 (DN2); also elsewhere on the board
USB_DP: J1.A6 (DP1), J1.B6 (DP2); also elsewhere on the board
~RESET: U5.8 (~RESET); also elsewhere on the board

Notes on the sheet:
PGND connects to GND at VCC bypass capacitor as per data sheet
J2 is used to diode or the different power inputs to this board depending on its desired configuration. Connect J2 to the sources of power required for this board. This can be external supply and/or the battery to be charged and discharged. This ensures the microcontroller will always have a source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
USB-C Socket
Power Enable

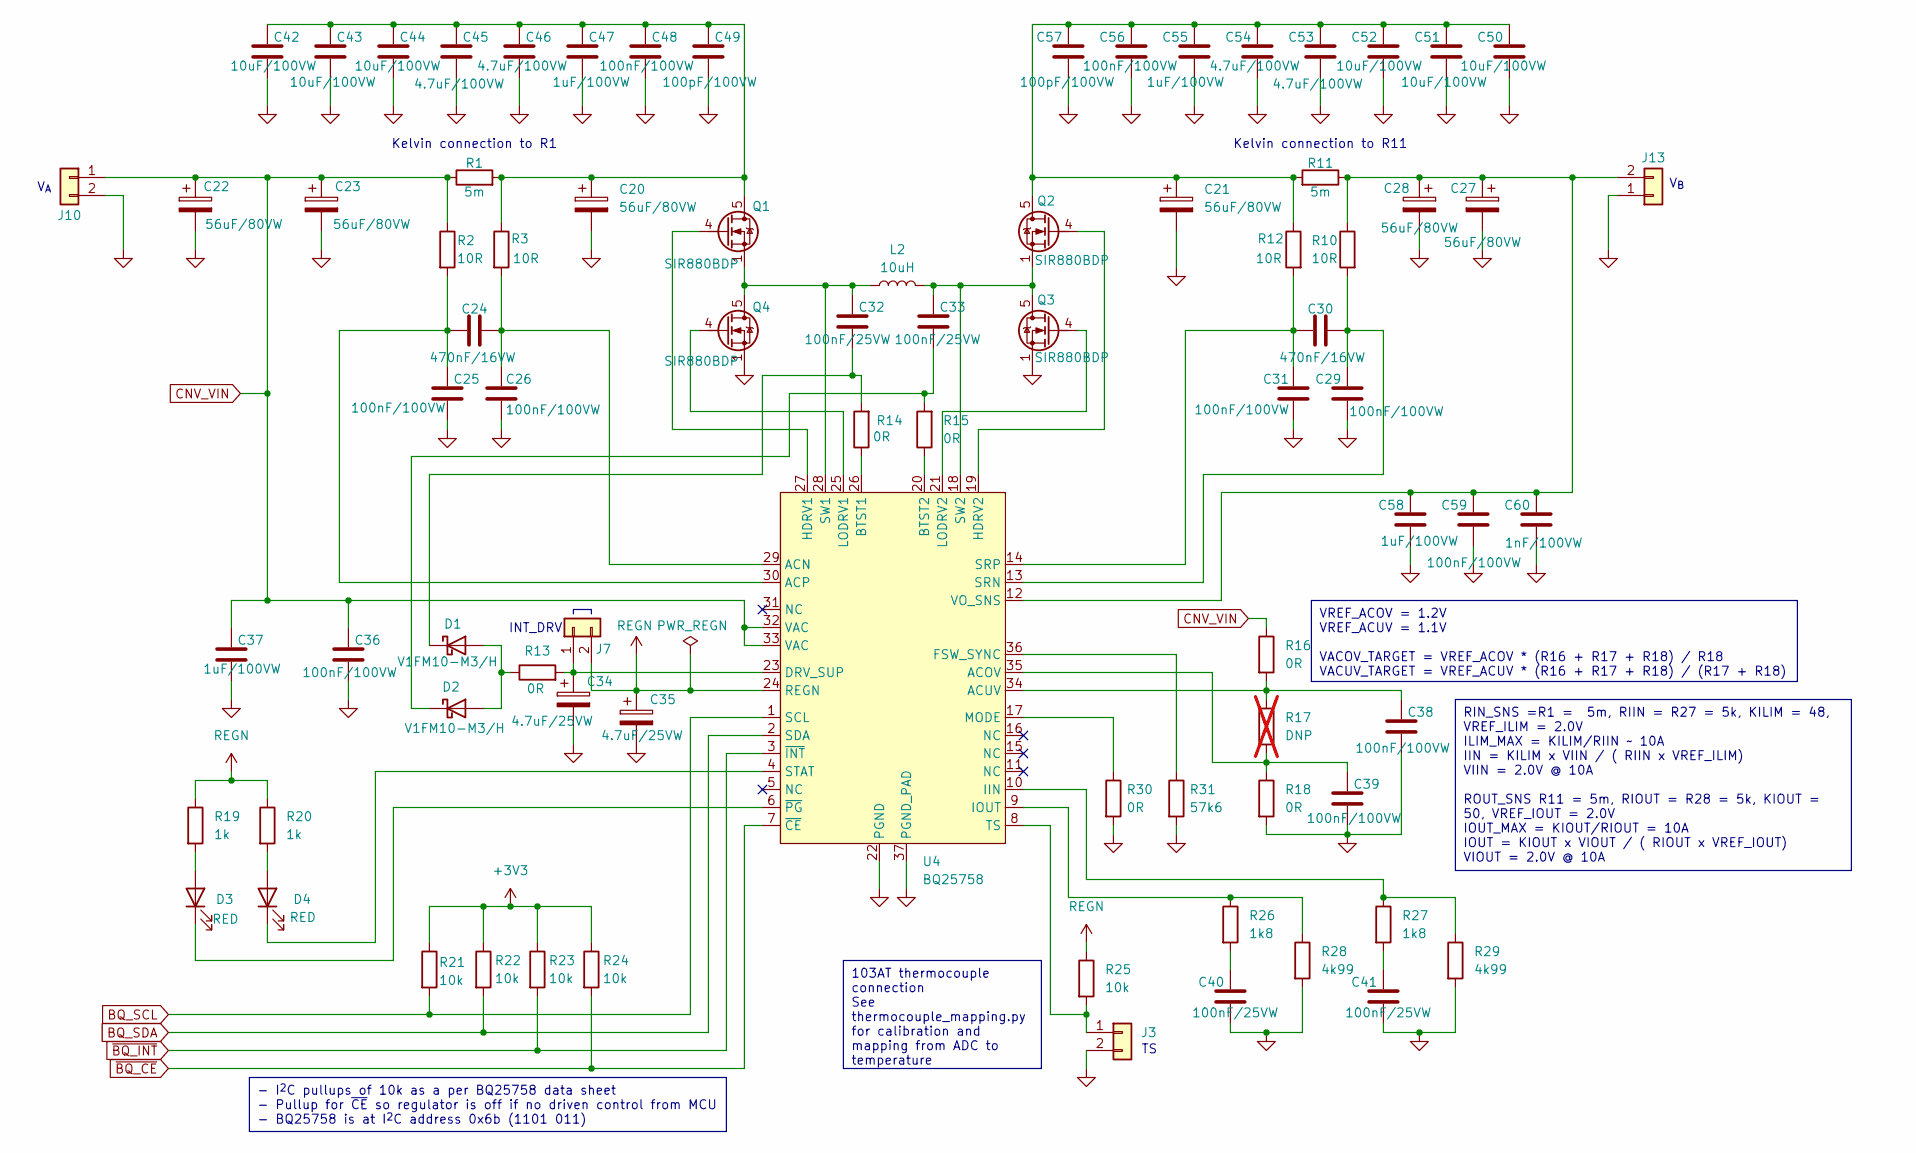
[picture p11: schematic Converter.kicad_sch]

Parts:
C20, C21, C22, C23, C27, C28: 56uF/80VW; CP_Elec_10x10.5; JLCPCB C128515
C24, C30: 470nF/16VW; C_0603_1608Metric; JLCPCB C1623
C25, C26, C29, C31, C36, C38, C39, C48, C56, C59: 100nF/100VW; C_1206_3216Metric; JLCPCB C1945
C32, C33, C40, C41: 100nF/25VW; C_0603_1608Metric; JLCPCB C1590
C34, C35: 4.7uF/25VW; C_0805_2012Metric; JLCPCB C1779
C37, C47, C55, C58: 1uF/100VW; C_1206_3216Metric; JLCPCB C13832
C42, C43, C44, C50, C51, C52: 10uF/100VW; C_1210_3225Metric; JLCPCB C5156756
C45, C46, C53, C54: 4.7uF/100VW; C_1210_3225Metric; JLCPCB C385986
C49, C57: 100pF/100VW; C_0805_2012Metric; JLCPCB C37456
C60: 1nF/100VW; C_0805_2012Metric; JLCPCB C15177
D1, D2: V1FM10-M3/H; D_SMF; JLCPCB C3758930
D3, D4: RED; LED_0603_1608Metric; JLCPCB C2286
J3, J7: CON2; PinHeader_1x02_P2.54mm_Vertical
J10, J13: Conn_01x02; PhoenixContact_MSTBVA_2,5_2-G-5,08_1x02_P5.08mm_Vertical
L2: 10uH; L_Wuerth_HCM-1350; Mouser 530-SCIHP1367-100M
Q1, Q2, Q3, Q4: SIR880BDP; POWERPAK-SO-8_L6.2-W5.2-P1.27-BL-EP; LCSC Part C5900133
R1, R11: 5m; RES-SMD_L10.0-W5.2; JLCPCB C481477
R2, R3, R10, R12: 10R; R_0603_1608Metric; JLCPCB C22859
R13, R14, R15, R16, R18, R30: 0R; R_0603_1608Metric; JLCPCB C21189
R17: DNP; R_0603_1608Metric; not fitted
R19, R20: 1k; R_0603_1608Metric; JLCPCB C21190
R21, R22, R23, R24, R25: 10k; R_0603_1608Metric; JLCPCB C25804
R26, R27: 1k8; R_0603_1608Metric; JLCPCB C4177
R28, R29: 4k99; R_0603_1608Metric; JLCPCB C2692815
R31: 57k6; R_0603_1608Metric; JLCPCB C23082
U4: BQ25758; QFN-36_L6.0-W5.0-P0.50-BL-EP-1; JLCPCB C33222334

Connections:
+3V3: R21.1, R22.1, R23.1, R24.1; also elsewhere on the board
BQ_SCL: R21.2, U4.1 (SCL); also elsewhere on the board
BQ_SDA: R22.2, U4.2 (SDA); also elsewhere on the board
CNV_VIN: C22.1, C23.1, C36.1, C37.1, J10.1, R1.1, R2.1, R16.1, U4.32 (VAC), U4.33 (VAC)
GND: C20.2, C21.2, C22.2, C23.2, C25.2, C26.2, C27.2, C28.2, C29.2, C31.2, C34.2, C35.2, C36.2, C37.2, C38.2, C39.2, C40.2, C41.2, C42.2, C43.2, C44.2, C45.2, C46.2, C47.2, C48.2, C49.2, C50.2, C51.2, C52.2, C53.2, C54.2, C55.2, C56.2, C57.2, C58.2, C59.2, C60.2, J3.2, J10.2, J13.1, Q3.1 (S), Q3.2 (S), Q3.3 (S), Q4.1 (S), Q4.2 (S), Q4.3 (S), R18.2, R28.2, R29.2, R30.2, R31.2, U4.22 (PGND), U4.37 (PGND_PAD); also elsewhere on the board
unnamed: C40.1, R26.2
unnamed: C41.1, R27.2
unnamed: D1.2 (A), D2.2 (A), R13.1
unnamed: C32.2, D1.1 (K), R14.2
unnamed: C33.2, D2.1 (K), R15.2
unnamed: D3.2 (A), R19.2
unnamed: D3.1 (K), U4.6 (~PG)
unnamed: D4.2 (A), R20.2
unnamed: D4.1 (K), U4.4 (STAT)
unnamed: J3.1, R25.2, U4.8 (TS)
unnamed: C34.1, J7.1, R13.2, U4.23 (DRV_SUP)
unnamed: C27.1, C28.1, C58.1, C59.1, C60.1, J13.2, R10.1, R11.1, U4.12 (VO_SNS)
unnamed: C20.1, C42.1, C43.1, C44.1, C45.1, C46.1, C47.1, C48.1, C49.1, Q1.5 (D), Q1.6 (D), Q1.7 (D), Q1.8 (D), Q1.9 (EP), R1.2, R3.1
unnamed: Q1.4 (G), U4.27 (HDRV1)
unnamed: C21.1, C50.1, C51.1, C52.1, C53.1, C54.1, C55.1, C56.1, C57.1, Q2.5 (D), Q2.6 (D), Q2.7 (D), Q2.8 (D), Q2.9 (EP), R11.2, R12.1
unnamed: Q2.4 (G), U4.19 (HDRV2)
unnamed: C33.1, L2.2, Q2.1 (S), Q2.2 (S), Q2.3 (S), Q3.5 (D), Q3.6 (D), Q3.7 (D), Q3.8 (D), Q3.9 (EP), U4.18 (SW2)
unnamed: Q3.4 (G), U4.21 (LODRV2)
unnamed: C32.1, L2.1, Q1.1 (S), Q1.2 (S), Q1.3 (S), Q4.5 (D), Q4.6 (D), Q4.7 (D), Q4.8 (D), Q4.9 (EP), U4.28 (SW1)
unnamed: Q4.4 (G), U4.25 (LODRV1)
unnamed: C24.2, C26.1, R3.2, U4.29 (ACN)
unnamed: C39.1, R17.2, R18.1, U4.35 (ACOV)
unnamed: C24.1, C25.1, R2.2, U4.30 (ACP)
unnamed: C38.1, R16.2, R17.1, U4.34 (ACUV)
unnamed: R14.1, U4.26 (BTST1)
unnamed: R15.1, U4.20 (BTST2)
unnamed: R31.1, U4.36 (FSW_SYNC)
unnamed: R27.1, R29.1, U4.10 (IIN)
unnamed: R26.1, R28.1, U4.9 (IOUT)
unnamed: R30.1, U4.17 (MODE)
unnamed: C29.1, C30.1, R10.2, U4.13 (SRN)
unnamed: C30.2, C31.1, R12.2, U4.14 (SRP)
REGN: C35.1, J7.2, R19.1, R20.1, R25.1, U4.24 (REGN)
~BQ_CE: R24.2, U4.7 (~CE); also elsewhere on the board
~BQ_INT: R23.2, U4.3 (~INT); also elsewhere on the board

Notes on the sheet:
103AT thermocouple connection See thermocouple_mapping.py for calibration and mapping from ADC to temperature
RIN_SNS =R1 = 5m, RIIN = R27 = 5k, KILIM = 48, VREF_ILIM = 2.0V ILIM_MAX = KILIM/RIIN ~ 10A IIN = KILIM x VIIN / ( RIIN x VREF_ILIM) VIIN = 2.0V @ 10A ROUT_SNS R11 = 5m, RIOUT = R28 = 5k, KIOUT = 50, VREF_IOUT = 2.0V IOUT_MAX = KIOUT/RIOUT = 10A IOUT = KIOUT x VIOUT / ( RIOUT x VREF_IOUT) VIOUT = 2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
VREF_ACOV = 1.2V VREF_ACUV = 1.1V VACOV_TARGET = VREF_ACOV * (R16 + R17 + R18) / R18 VACUV_TARGET = VREF_ACUV * (R16 + R17 + R18) / (R17 + R18)
- I^{2}C pullups of 10k as a per BQ25758 data sheet - Pullup for ~{CE} so regulator is off if no driven control from MCU - BQ25758 is at I^{2}C address 0x6b (1101 011)
Kelvin connection to R11
V_{A}
V_{B}
INT_DRV
Kelvin connection to R1

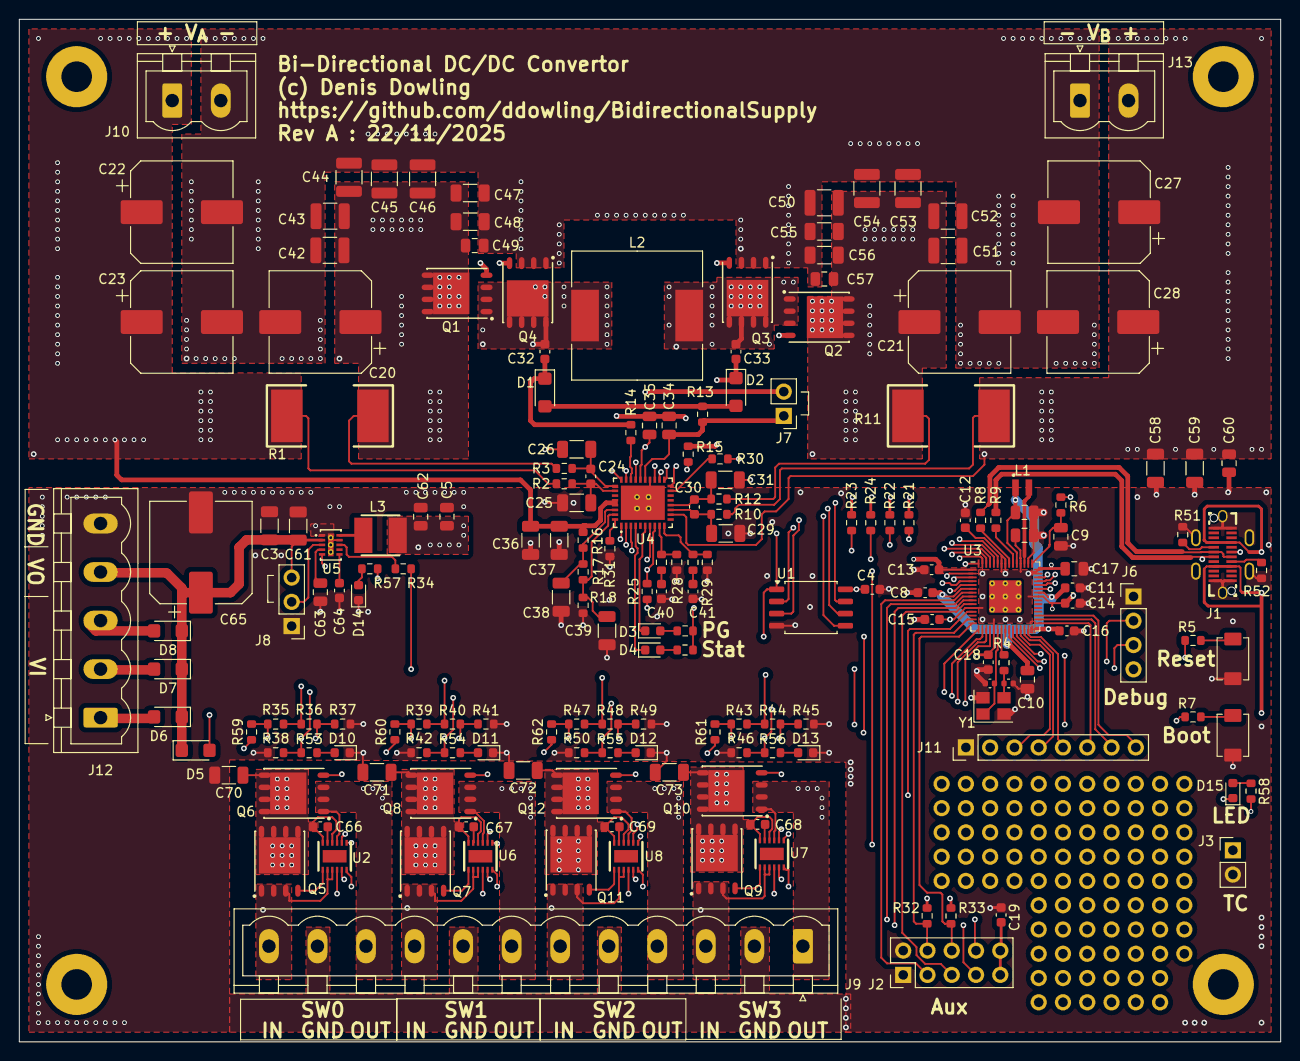
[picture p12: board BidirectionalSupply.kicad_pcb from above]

Board: 4 copper layers, 132.0 x 107.0 mm, 190 parts (0 on the bottom side), 132 nets.

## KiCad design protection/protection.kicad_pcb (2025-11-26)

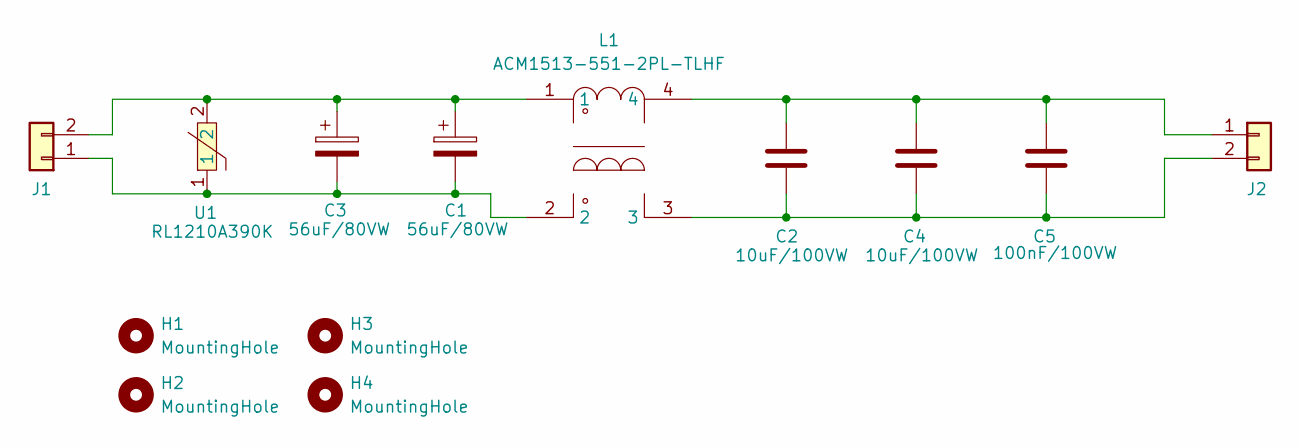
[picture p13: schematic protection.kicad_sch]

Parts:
C1, C3: 56uF/80VW; CP_Elec_10x10.5; LCSC Part C128515
C2, C4: 10uF/100VW; C_1210_3225Metric; LCSC Part C5156756
C5: 100nF/100VW; C_1206_3216Metric; LCSC Part C1945
H1, H2, H3, H4: MountingHole; MountingHole_3.2mm_M3_DIN965_Pad
J1, J2: Conn_01x02; PhoenixContact_MSTBVA_2,5_2-G-5,08_1x02_P5.08mm_Vertical
L1: ACM1513-551-2PL-TLHF; FILTER-SMD_4P-L15.0-W13.0-BL; LCSC Part C111471
U1: RL1210A390K; R1210; LCSC Part C19267881

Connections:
unnamed: C1.2, C3.2, J1.1, L1.2, U1.1
unnamed: C1.1, C3.1, J1.2, L1.1, U1.2
unnamed: C2.1, C4.1, C5.1, J2.1, L1.4
unnamed: C2.2, C4.2, C5.2, J2.2, L1.3

Board: 2 copper layers, 13 parts (0 on the bottom side), 4 nets, no tracks yet.

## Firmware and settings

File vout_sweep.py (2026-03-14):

#!/usr/bin/env python3
# Copyright (c) 2026 Denis Dowling (dpd@opsol.com.au)
"""
Automated calibration system integrating IT8511 DC load control
with BidirectionalSupply ADC calibration.

Requires: pip install itech_serial pyserial
"""

import sys
import time
import pandas as pd
import numpy as np
import json
import serial
from pathlib import Path
from itech_serial import IT8500

REGISTRY_PATH = Path(__file__).parent / 'board_registry.json'


class BoardConnection:
    """Persistent connection to RP2350 board via MicroPython raw REPL"""

    def __init__(self, port='/dev/ttyACM0', baudrate=115200, timeout=3):
        self.port = port
        self.baudrate = baudrate
        self.timeout = timeout
        self.ser = None

    def connect(self):
        """Open serial port and enter MicroPython raw REPL"""
        self.ser = serial.Serial(self.port, self.baudrate, timeout=self.timeout)
        time.sleep(0.1)
        # Interrupt any running code
        self.ser.write(b'\x03\x03')
        time.sleep(0.2)
        self.ser.read(self.ser.in_waiting)
        # Enter raw REPL (Ctrl-A)
        self.ser.write(b'\x01')
        time.sleep(0.2)
        resp = self.ser.read(self.ser.in_waiting)
        if b'raw REPL' not in resp:
            raise ConnectionError(f"Failed to enter raw REPL: {resp}")
        print(f"Connected to RP2350 on {self.port}")

    def exec(self, cmd, timeout=10):
        """Execute command in raw REPL, return stdout string"""
        self.ser.write(cmd.encode() + b'\x04')
        buf = b''
        deadline = time.time() + timeout
        while time.time() < deadline:
            chunk = self.ser.read(self.ser.in_waiting or 1)
            if chunk:
                buf += chunk
                if b'\x04>' in buf:
                    break
        # Parse: OK<stdout>\x04<stderr>\x04>
        if buf.startswith(b'OK'):
            buf = buf[2:]
        parts = buf.split(b'\x04')
        stdout = parts[0].decode().strip() if parts else ''
        stderr = parts[1].decode().strip() if len(parts) > 1 else ''
        if stderr:
            print(f"  [RP2350 error: {stderr}]")
        return stdout

    def setup_board(self):
        """Initialize board hardware and ADC"""
        self.exec("import board", timeout=5)
        resp = self.exec("board.setup()", timeout=15)
        if resp:
            print(resp)
        self.exec("board.bq.setup_adc()")
        self.exec("board.bq.set_enabled(True)")
        time.sleep(0.5)
        self.hardware_id = self.get_hardware_id()
        print(f"Board initialized with ADC enabled (HW ID: {self.hardware_id})")

    def get_hardware_id(self):
        """Read the unique hardware ID from the RP2350"""
        resp = self.exec("import ubinascii, machine; print('RP2350_' + ubinascii.hexlify(machine.unique_id()).decode('ascii')[-8:].upper())")
        return resp.strip()

    def close(self):
        """Exit raw REPL and close serial port"""
        if self.ser and self.ser.is_open:
            self.ser.write(b'\x02')  # Ctrl-B to exit raw REPL
            time.sleep(0.1)
            self.ser.close()
            print(f"Disconnected from RP2350")


class AutomatedCalibration:
    def __init__(self, it8511_port='/dev/it8511', board_port='/dev/ttyACM0', baudrate=4800):
        """
        Initialize automated calibration system

        Args:
            it8511_port: Serial port for IT8511 electronic load
            board_port: Serial port for RP2350 board
            baudrate: Baud rate for IT8511 communication (default 4800)
        """
        self.it8511_port = it8511_port
        self.board_port = board_port
        self.baudrate = baudrate
        self.load = None
        self.board = None

    def load_board_registry(self):
        """Load board registry and look up the connected board"""
        try:
            with open(REGISTRY_PATH) as f:
                registry = json.load(f)
        except FileNotFoundError:
            print(f"Board registry not found at {REGISTRY_PATH}")
            registry = {"boards": {}}

        hw_id = self.board.hardware_id
        if hw_id in registry['boards']:
            info = registry['boards'][hw_id]
            self.board_number = info['board_number']
            print(f"Identified as Board #{self.board_number} ({info.get('description', '')})")
        else:
            print(f"Unknown board {hw_id} - not in registry")
            self.board_number = self._register_new_board(registry, hw_id)

    def _register_new_board(self, registry, hw_id):
        """Prompt user to register a new board"""
        existing = [b['board_number'] for b in registry['boards'].values()]
        next_num = max(existing, default=0) + 1
        resp = input(f"Register as Board #{next_num}? (y/N or enter number): ").strip()
        if resp.lower() == 'y':
            board_num = next_num
        elif resp.isdigit():
            board_num = int(resp)
        else:
            print("Board not registered, using 0")
            return 0

        registry['boards'][hw_id] = {
            "board_number": board_num,
            "description": f"Board #{board_num}",
            "calibrated": False,
            "calibration_date": None,
            "notes": ""
        }
        with open(REGISTRY_PATH, 'w') as f:
            json.dump(registry, f, indent=4)
        print(f"Registered {hw_id} as Board #{board_num}")
        return board_num

    def setup_board(self):
        """Initialize persistent connection to RP2350 board"""
        try:
            self.board = BoardConnection(self.board_port)
            self.board.connect()
            self.board.setup_board()
            self.load_board_registry()
            return True
        except Exception as e:
            print(f"Error setting up board: {e}")
            return False

    def setup_electronic_load(self):
        """Initialize and configure IT8511 electronic load"""
        try:
            self.load = IT8500(self.it8511_port, baudrate=self.baudrate)
            self.load.control_set_remote()

            info = self.load.identify()
            print(f"Connected to: {info}")

            self.load.mode_set('cc')
            self.load.max_voltage_set(50.0)
            self.load.max_current_set(5.0)
            self.load.max_power_set(100.0)

            print("IT8511 setup complete")
            return True

        except Exception as e:
            print(f"Error setting up IT8511: {e}")
            return False

    def set_load_current(self, current_a):
        """Set electronic load current"""
        try:
            self.load.constant_current_set(current_a)
            print(f"Set load current: {current_a}A")
        except Exception as e:
            print(f"Error setting load current: {e}")

    def enable_load(self):
        """Enable electronic load"""
        try:
            self.load.enable()
            print("Electronic load enabled")
        except Exception as e:
            print(f"Error enabling load: {e}")

    def disable_load(self):
        """Disable electronic load (safety)"""
        try:
            self.load.disable()
            print("Electronic load disabled")
        except Exception as e:
            print(f"Error disabling load: {e}")

    def get_board_readings(self):
        """Get voltage and current readings from RP2350 board"""
        resp = self.board.exec(
            "print(f'{board.bq.get_vout_adc():.6f},{board.bq.get_iout_adc():.6f}')"
        )
        try:
            parts = resp.split(',')
            return {
                'vout_raw': float(parts[0]),
                'iout_raw': float(parts[1]),
            }
        except (ValueError, IndexError):
            print(f"  Failed to parse board readings: {resp}")
            return None

    def get_it8511_measurements(self):
        """Get calibrated voltage/current measurements from IT8511"""
        try:
            measurements = self.load.measure()
            return {
                'voltage': measurements['voltage'],
                'current': measurements['current'],
                'power': measurements['power'],
            }
        except Exception as e:
            print(f"Error reading IT8511 measurements: {e}")
            return None

    def automated_voltage_calibration(self, voltage_range=(3.5, 48.0), num_points=45, load_current=0.1):
        """
        Run automated voltage calibration using IT8511 as calibrated reference

        Args:
            voltage_range: (min_v, max_v) tuple
            num_points: Number of voltage points to test
            load_current: Constant load current in Amps
        """

        print("=" * 60)
        print("Starting Automated Voltage Calibration")
        print("=" * 60)

        # Safety check
        response = input(f"This will set {load_current}A load and sweep {voltage_range[0]}V to {voltage_range[1]}V. Continue? (y/N): ")
        if response.lower() != 'y':
            print("Calibration cancelled")
            return

        # Setup instruments
        if not self.setup_board():
            print("Failed to setup board connection")
            return
        if not self.setup_electronic_load():
            print("Failed to setup electronic load")
            return

        try:
            # Set constant load current
            self.set_load_current(load_current)
            self.enable_load()

            print(f"Load enabled at {load_current}A")
            print("Waiting 5 seconds for system to stabilize...")
            time.sleep(5)

            # Generate voltage points
            voltages = np.linspace(voltage_range[0], voltage_range[1], num_points)

            calibration_data = []

            for i, set_voltage in enumerate(voltages):
                print(f"Point {i+1}/{num_points}: Setting {set_voltage:.3f}V")

                # Set output voltage on RP2350
                self.board.exec(f"board.bq.set_output_voltage_limit({set_voltage})")

                # Wait for settling
                time.sleep(2)

                # Take multiple readings for statistics
                board_readings = []
                it8511_readings = []

                for _ in range(5):
                    board_data = self.get_board_readings()
                    it8511_data = self.get_it8511_measurements()

                    if board_data and it8511_data:
                        board_readings.append(board_data['vout_raw'])
                        it8511_readings.append(it8511_data['voltage'])
                    time.sleep(0.5)

                if board_readings and it8511_readings:
                    adc_voltage = np.mean(board_readings)
                    adc_std = np.std(board_readings)
                    reference_voltage = np.mean(it8511_readings)  # IT8511 calibrated measurement
                    reference_std = np.std(it8511_readings)

                    error_mv = (adc_voltage - reference_voltage) * 1000
                    error_percent = (error_mv / (reference_voltage * 1000)) * 100

                    # Calculate setpoint error (command vs actual delivery)
                    setpoint_error_mv = (reference_voltage - set_voltage) * 1000
                    setpoint_error_percent = (setpoint_error_mv / (set_voltage * 1000)) * 100

                    calibration_data.append({
                        'set_voltage': set_voltage,
                        'adc_voltage': adc_voltage,
                        'adc_std': adc_std,
                        'reference_voltage': reference_voltage,
                        'reference_std': reference_std,
                        'adc_error_mv': error_mv,
                        'adc_error_percent': error_percent,
                        'setpoint_error_mv': setpoint_error_mv,
                        'setpoint_error_percent': setpoint_error_percent,
                        'board_readings': board_readings,
                        'it8511_readings': it8511_readings
                    })

                    print(f"  Set: {set_voltage:.3f}V → Actual: {reference_voltage:.6f}V (SP_err: {setpoint_error_mv:.1f}mV)")
                    print(f"  ADC: {adc_voltage:.6f}V → Error: {error_mv:.1f}mV ({error_percent:.2f}%)")
                else:
                    print(f"  Failed to get readings for {set_voltage:.3f}V")

            # Save results
            df = pd.DataFrame(calibration_data)
            df['board_number'] = self.board_number
            df['hardware_id'] = self.board.hardware_id
            timestamp = int(time.time())
            filename = f"calibration_results/board{self.board_number}_voltage_cal_{timestamp}.csv"
            df.to_csv(filename, index=False)

            print(f"\nCalibration complete! Results saved to {filename}")
            print(f"Board #{self.board_number} ({self.board.hardware_id})")
            print(f"Collected {len(calibration_data)} data points")

            # Fit quadratic correction and upload to board
            if len(calibration_data) >= 3:
                self.apply_vout_calibration(df)

            # Generate analysis plots
            self.generate_analysis_plots(df, timestamp)

        finally:
            # Always disable load and close board for safety
            print("\nDisabling electronic load...")
            self.disable_load()
            self.board.close()
            print("Calibration finished safely")

    def apply_vout_calibration(self, df):
        """Fit quadratic correction from calibration data and upload to board"""
        adc_values = df['adc_voltage'].values
        ref_values = df['reference_voltage'].values
        error_mv = (adc_values - ref_values) * 1000

        # Fit quadratic: error_mv = a*v^2 + b*v + c
        coeffs = np.polyfit(adc_values, error_mv, 2)
        a, b, c = float(coeffs[0]), float(coeffs[1]), float(coeffs[2])

        # Calculate residual
        fitted = np.polyval(coeffs, adc_values)
        residual = error_mv - fitted
        rms_error = float(np.sqrt(np.mean(residual**2)))

        print(f"\nQuadratic fit: {a:.6f}*V^2 + {b:.4f}*V + {c:.2f} mV")
        print(f"RMS residual: {rms_error:.1f}mV, Max: {np.abs(residual).max():.1f}mV")

        # Upload calibration to board
        print("Uploading calibration to board...")
        self.board.exec(f"import calibration as _cal")
        self.board.exec(f"_c = _cal.Calibration()")
        self.board.exec(f"_c.set_vout_calibration(quad_a={a}, quad_b={b}, quad_c={c}, rms_error_mv={rms_error})")
        self.board.exec(f"_c.set_calibration_date('{time.strftime('%Y-%m-%d')}')")
        self.board.exec(f"_c.set_board_id()")
        self.board.exec(f"_c.save()")

        # Verify
        resp = self.board.exec("print(_c.get_calibration_summary())")
        print(f"Board calibration:\n{resp}")

        # Update registry
        try:
            with open(REGISTRY_PATH) as f:
                registry = json.load(f)
            hw_id = self.board.hardware_id
            if hw_id in registry['boards']:
                registry['boards'][hw_id]['calibrated'] = True
                registry['boards'][hw_id]['calibration_date'] = time.strftime('%Y-%m-%d')
                registry['boards'][hw_id]['notes'] = f"quad_a={a:.6f}, quad_b={b:.4f}, quad_c={c:.2f}"
                with open(REGISTRY_PATH, 'w') as f:
                    json.dump(registry, f, indent=4)
        except Exception as e:
            print(f"Warning: could not update registry: {e}")

    def generate_analysis_plots(self, df, timestamp):
        """Generate matplotlib analysis plots"""
        try:
            # Import your existing analysis functions
            sys.path.append('calibration_results')
            # You can adapt your existing analyze_calibration.py functions here
            print(f"Analysis plots would be generated for dataset {timestamp}")

        except Exception as e:
            print(f"Error generating plots: {e}")

    def automated_current_calibration(self, current_range=(0.1, 5.0), num_points=25, test_voltage=12.0):
        """
        Run automated current calibration using IT8511 as calibrated reference

        Args:
            current_range: (min_a, max_a) tuple for current sweep
            num_points: Number of current points to test
            test_voltage: Fixed voltage for current testing
        """

        print("=" * 60)
        print("Starting Automated Current Calibration")
        print("=" * 60)

        # Safety check
        response = input(f"This will sweep current from {current_range[0]}A to {current_range[1]}A at {test_voltage}V. Continue? (y/N): ")
        if response.lower() != 'y':
            print("Calibration cancelled")
            return

        # Setup instruments
        if not self.setup_board():
            print("Failed to setup board connection")
            return
        if not self.setup_electronic_load():
            print("Failed to setup electronic load")
            return

        try:
            # Set fixed test voltage
            print(f"Setting output voltage to {test_voltage}V")
            self.board.exec(f"board.bq.set_output_voltage_limit({test_voltage})")
            time.sleep(3)  # Allow voltage to settle

            # Generate current points
            currents = np.linspace(current_range[0], current_range[1], num_points)

            calibration_data = []

            for i, set_current in enumerate(currents):
                print(f"Point {i+1}/{num_points}: Setting {set_current:.3f}A load")

                # Set load current
                self.set_load_current(set_current)
                self.enable_load()

                # Wait for settling
                time.sleep(3)

                # Take multiple readings for statistics
                board_readings = []
                it8511_readings = []
                it8511_voltage_readings = []

                for _ in range(5):
                    board_data = self.get_board_readings()
                    it8511_data = self.get_it8511_measurements()

                    if board_data and it8511_data:
                        board_readings.append(board_data['iout_raw'])
                        it8511_readings.append(it8511_data['current'])
                        it8511_voltage_readings.append(it8511_data['voltage'])
                    time.sleep(0.5)

                if board_readings and it8511_readings:
                    adc_current = np.mean(board_readings)
                    adc_std = np.std(board_readings)
                    reference_current = np.mean(it8511_readings)  # IT8511 calibrated measurement
                    reference_std = np.std(it8511_readings)
                    reference_voltage = np.mean(it8511_voltage_readings)

                    error_ma = (adc_current - reference_current) * 1000
                    error_percent = (error_ma / (reference_current * 1000)) * 100

                    calibration_data.append({
                        'set_current': set_current,
                        'adc_current': adc_current,
                        'adc_std': adc_std,
                        'reference_current': reference_current,
                        'reference_std': reference_std,
                        'reference_voltage': reference_voltage,
                        'error_ma': error_ma,
                        'error_percent': error_percent,
                        'board_readings': board_readings,
                        'it8511_readings': it8511_readings,
                        'test_voltage': test_voltage
                    })

                    print(f"  ADC: {adc_current:.6f}A, Ref: {reference_current:.6f}A, Error: {error_ma:.1f}mA ({error_percent:.2f}%)")
                    print(f"  IT8511 voltage: {reference_voltage:.3f}V")
                else:
                    print(f"  Failed to get readings for {set_current:.3f}A")

            # Save results
            df = pd.DataFrame(calibration_data)
            df['board_number'] = self.board_number
            df['hardware_id'] = self.board.hardware_id
            timestamp = int(time.time())
            filename = f"calibration_results/board{self.board_number}_current_cal_{timestamp}.csv"
            df.to_csv(filename, index=False)

            print(f"\nCurrent calibration complete! Results saved to {filename}")
            print(f"Board #{self.board_number} ({self.board.hardware_id})")
            print(f"Collected {len(calibration_data)} data points")

            # Generate analysis plots
            self.generate_current_analysis_plots(df, timestamp)

        finally:
            # Always disable load and close board for safety
            print("\nDisabling electronic load...")
            self.disable_load()
            self.board.close()
            print("Current calibration finished safely")

    def generate_current_analysis_plots(self, df, timestamp):
        """Generate matplotlib analysis plots for current calibration"""
        try:
            print(f"Current analysis plots would be generated for dataset {timestamp}")
            # Similar to voltage analysis but for current data

        except Exception as e:
            print(f"Error generating current plots: {e}")
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

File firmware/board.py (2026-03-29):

# Copyright (c) 2026 Denis Dowling (dpd@opsol.com.au)
from machine import Pin, ADC, PWM, I2C, Timer
from BQ25758 import BQ25758
from calibration import Calibration
from display import display_convertor_info, display_blank, display_error

bq_sda = Pin(0)
bq_scl = Pin(1)
bq_int = Pin(2, Pin.IN)

# Inverted logic on this pin. Want output to stay high until explicitly enabled
bq_ce = Pin(3, Pin.OUT, True)

# LED on Pin(8), active-low. PWM: duty 0 = full on, 65535 = off.
_led_pwm = PWM(Pin(8, Pin.OUT), freq=100_000, duty_u16=65535)


# Ideal Diode switches
sw0_en = Pin(12, Pin.OUT)
sw1_en = Pin(13, Pin.OUT)
sw2_en = Pin(14, Pin.OUT)
sw3_en = Pin(15, Pin.OUT)
sw0_vsense = ADC(Pin(26))
sw1_vsense = ADC(Pin(27))
sw2_vsense = ADC(Pin(28))
sw3_vsense = ADC(Pin(29))

bq_i2c = I2C(0, sda=bq_sda, scl=bq_scl)

bq = BQ25758(i2c_bus=bq_i2c, chip_enable_pin=bq_ce)

# Load calibration data
calibration = Calibration()

# RP2350 ADC scaling for the ideal diode switches
R35 = 97.6
R36 = 3.1
R37 = 2.1
ADC_SCALE = (3.3 / 65535) * (R35 + R36 + R37) / (R36 + R37)

def _bq_connect():
    '''Initialise the BQ25758 and enable its ADC.

    Called on first boot and again whenever the chip loses power and
    is_detected() returns False. bq.setup() issues REG_RST which clears
    all BQ25758 registers, so load_startup() must be called afterwards
    to restore any saved limits.
    '''
    bq.setup()
    bq.setup_adc()

def setup():
    _led_pwm.duty_u16(0)  # LED on during setup

    display_blank()

    # Display board identification
    print(f"=== BidirectionalSupply Board ===")
    print(f"Board ID: {calibration.get_board_id()}")
    print(f"Hardware ID: {calibration.get_hardware_id()}")
    if calibration.is_calibrated():
        print(f"Calibrated: {calibration.get_calibration_date()}")
    else:
        print("Calibrated: No calibration data")

    # Look for devices on the bq_i2c bus
    devices = bq_i2c.scan()

    print(f"Found {len(devices)} devices on bq_i2c bus")
    if len(devices) == 0:
        raise RuntimeError("No I2C devices on convertor bus")

    for d in devices:
        print(f"Device at address {d:02x}")

    _bq_connect()

    print("Initialised BQ25758")

    _led_pwm.duty_u16(65535)  # LED off after setup

def _switch_to_enable_pin(switch_num):
    if switch_num == 0:
        return sw0_en
    elif switch_num == 1:
        return sw1_en
    elif switch_num == 2:
        return sw2_en
    elif switch_num == 3:
        return sw3_en
    else:
        raise ValueError("Bad switch_num")

def _switch_to_adc(switch_num):
    if switch_num == 0:
        return sw0_vsense
    elif switch_num == 1:
        return sw1_vsense
    elif switch_num == 2:
        return sw2_vsense
    elif switch_num == 3:
        return sw3_vsense
    else:
        raise ValueError("Bad switch_num")

def set_switch(switch_num, state):
    p = _switch_to_enable_pin(switch_num)
    p.value(state)

def get_switch(switch_num):
    p = _switch_to_enable_pin(switch_num)
    return p.value()

_die_temp_adc = ADC(4)  # RP2350 internal temperature sensor

def get_die_temp():
    '''Return RP2350 die temperature in Celsius.
    Uses the internal ADC channel 4 and conversion constants from the
    RP2350 datasheet. Accuracy is typically ±a few degrees.
    '''
    reading = _die_temp_adc.read_u16() * 3.3 / 65535
    return 27 - (reading - 0.706) / 0.001721

def get_switch_vsense(switch_num):
    adc = _switch_to_adc(switch_num)
    raw = adc.read_u16()
    return raw * ADC_SCALE
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

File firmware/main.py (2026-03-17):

# Copyright (c) 2026 Denis Dowling (dpd@opsol.com.au)
import board
from display import display_error


def _load_role(filename='role.dat'):
    '''Read role.dat and initialise the board role.

    Supported roles:
        role=converter   — general-purpose DC/DC converter (default).
                           startup.dat provides voltage/current limits.
        role=charger     — battery charger. Requires a profile= line
                           naming a ChargingProfile from charger.py.

    Example role.dat for charger:
        role=charger
        profile=LIFEPO4_2S_5AH

    Lines beginning with # are comments. Unknown keys are ignored.
    If role.dat is absent the board defaults to converter mode.
    '''
    try:
        with open(filename, 'r') as f:
            lines = f.read().splitlines()
    except OSError:
        return  # No role.dat — default converter behaviour

    params = {}
    for line in lines:
        line = line.strip()
        if not line or line.startswith('#'):
            continue
        if '=' in line:
            k, _, v = line.partition('=')
            params[k.strip()] = v.strip()

    role = params.get('role', 'converter')
    print(f'Role: {role}')

    if role == 'charger':
        import charger as _charger
        profile_name = params.get('profile', '')
        profile = getattr(_charger, profile_name, None)
        if profile is None:
            raise ValueError(f'role.dat: unknown profile: {profile_name!r}')
        print(f'Charger profile: {profile.name}')
        board.set_charger(_charger.BatteryCharger(profile))

    elif role == 'converter':
        pass  # startup.dat already applied by load_startup()

    else:
        raise ValueError(f'role.dat: unknown role: {role!r}')


board.monitor(True)

try:
    board.setup()
    board.load_startup()
    _load_role()

except Exception as e:
    display_error(str(e))

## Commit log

2025-11-05 Added RP2350 reference design as I will be using these components in this application
    [BidirectionalSupply.kicad_pcb, BidirectionalSupply.kicad_sch, RP2350_60QFN_minimal.kicad_pcb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]
2025-11-07 WIP checkin of schematic
    [BidirectionalSupply.kicad_sch, Converter.kicad_sch, Microcontroller.kicad_sch]
2025-11-07 WIP checkin * Added most of the JLCPCB part numbers * Added most of the component footprints * Connected up microcontroller and dc/dc converter
    [BidirectionalSupply.kicad_sch, Converter.kicad_sch, Microcontroller.kicad_sch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]
2025-11-09 Cleaned up share library Added switchmode 3v3 supply
    [BidirectionalSupply.csv, BidirectionalSupply.kicad_sch, Ideal Diode Switch.kicad_sch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]
2025-11-11 Schematic is now mostly complete. Will review and then move onto the PCB layout
    [Converter.kicad_sch, Ideal Diode Switch.kicad_sch, Microcontroller.kicad_sch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]
2025-11-11 Checked all DC/DC converter capacitors Some part substitution to preference in stock items
    [BidirectionalSupply.csv, Converter.kicad_sch, Ideal Diode Switch.kicad_sch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]
2025-11-11 Add BOM csv
    [BidirectionalSupply.csv]
2025-11-13 All components placed on board and most 3D shapes are present
    [BidirectionalSupply.kicad_pcb, Converter.kicad_sch, Ideal Diode Switch.kicad_sch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]
2025-11-19 - Routed board with all fixable DRC errors and warnings fixed
    [BidirectionalSupply.kicad_pcb, Converter.kicad_sch, Ideal Diode Switch.kicad_sch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]
2025-11-20 Added summary page Added prototyping area to PCB
    [BidirectionalSupply.kicad_pcb, BidirectionalSupply.kicad_sch, Converter.kicad_sch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]
2025-11-21 Ready for trial submit to JLCPCB
    [BidirectionalSupply.kicad_pcb, BidirectionalSupply.kicad_sch, Converter.kicad_sch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]
2025-11-22 * Added the JLCPCB Fabrication Plugin into KiCad and use this for the exports * Fixed problem detected with capacitor footprint for C42, C43, C44, C50, C51, C52
    [BidirectionalSupply.csv, BidirectionalSupply.kicad_pcb, Converter.kicad_sch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]
2025-11-24 Start of some firmware
    [BidirectionalSupply.kicad_pcb, Ideal Diode Switch.kicad_sch]
2025-11-26 Removed the included RP2350 minimal board as should not be needed for symbols any more.
    [RP2350_60QFN_minimal.kicad_pcb, RP2350_60QFN_minimal.kicad_sch, RP2350_QFN60.step]
2025-11-26 Added a design for a simple MOV and common mode choke input protection circuit
    [protection.kicad_pcb, protection.kicad_sch]
2025-11-26 Update to the title block
    [BidirectionalSupply.kicad_sch, Converter.kicad_sch, Ideal Diode Switch.kicad_sch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]
2025-11-27 Designs as submitted on 27/11/2025
    [BidirectionalSupply.kicad_pcb]
2026-02-16 Add comprehensive automated calibration system
    - automated_calibration.py: Full automation with IT8511 electronic load
    * Voltage calibration with IT8511 as calibrated reference
    * Current calibration with load current sweeping
    * Dual calibration: ADC correction + setpoint correction
    * Safety features and statistical analysis
    * Menu-driven workflow for flexible testing
    - firmware/calibration.py: JSON-based calibration data management
    * Automatic board ID detection using RP2350 unique hardware ID
    * Atomic file writes with backup/recovery system
    * Calibrated ADC reading functions with gain/offset correction
    - firmware/detailed_calibration.py: High-resolution data collection
    *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
    [BQ25758.py, automated_calibration.py, board.py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]
2026-02-17 Replace mpremote subprocess calls with itech_serial and raw REPL
    Use itech_serial.IT8500 package for IT8511 DC load control instead of
    the old commented-out dcload library. Replace mpremote subprocess exec
    calls with a persistent serial connection to the RP2350 using
    MicroPython's raw REPL protocol, avoiding soft resets between commands
    and enabling tight timing between board ADC and IT8511 measurements.
    [automated_calibration.py]
2026-02-17 Add quadratic ADC voltage correction to BQ25758 driver
    Apply a quadratic correction to get_vout_adc() derived from a 94-point
    calibration sweep against an IT8511 DC load with Kelvin sense. Reduces
    ADC voltage error from ~160-212mV to under 8mV across 3.5-50V range.
    Coefficients: 0.056768*V^2 - 2.4064*V - 182.57 mV
    [BQ25758.py]
2026-02-17 Add board registry and tag calibration data with board number
    Introduce board_registry.json to map RP2350 hardware IDs to board
    numbers, supporting multi-board calibration. Unknown boards are
    prompted for registration on first connection. Calibration CSV
    filenames and data now include board number and hardware ID.
    Board #1 (RP2350_1E017096) registered with voltage sweep data.
    [board1_voltage_sweep_20260218.csv, board1_voltage_sweep_fine_20260218.csv]
2026-02-17 Move ADC quadratic correction to per-board calibration.dat
    Remove hardcoded quadratic coefficients from BQ25758.py and store them
    in calibration.dat as quad_a/quad_b/quad_c per board. calibration.py
    applies the correction in calibrate_vout_adc(). automated_calibration.py
    now fits and uploads coefficients after a voltage sweep.
    Board #2 (RP2350_B1F4049F) calibrated and verified <9mV accuracy.
    Board #1: 0.056768*V^2 - 2.4064*V - 182.57 mV
    Board #2: 0.061198*V^2 - 5.7726*V - 161.83 mV
    [board2_voltage_sweep_fine_20260218.csv]
2026-02-17 Add Board #1 calibration.dat with quadratic VOUT coefficients
    Pre-generated calibration file for Board #1 (RP2350_1E017096) to be
    uploaded when the board is next connected.
2026-02-17 Add Board #2 and #3 calibration data
    Board #2: quad_a=0.061198, quad_b=-5.7726, quad_c=-161.83
    Board #3: quad_a=0.061846, quad_b=-6.0615, quad_c=-153.58 (RMS 3.5mV)
    Both calibrated across 3.5-50V range with <9mV accuracy.
    [board3_voltage_sweep_fine_20260218.csv]
2026-02-18 Added board #4 and #5 calibration data
    [board4_voltage_sweep_fine_20260218.csv, board5_voltage_sweep_fine_20260218.csv]
2026-02-18 Complete VOUT ADC calibration for all 5 boards
    Board #4 (RP2350_F714B131): quad_a=0.073990, quad_b=-8.9779, quad_c=-141.29
    Board #5 (RP2350_260E44FE): quad_a=0.057370, quad_b=-1.3903, quad_c=-177.02
    All boards achieve <4mV RMS after quadratic correction across 3.5-50V.
    Added 5-board comparison plot.
2026-02-18 Fix Board #2 data in calibration comparison plot
    Board #2 CSV contained corrected ADC values (Board #1's correction
    applied). Reversed the correction to recover raw ADC readings so
    all 5 boards plot consistently.
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2026-03-01 Refactor calibration.py with proper LinearCalibration and QuadraticCalibration classes
    Wire LinearCalibration and QuadraticCalibration into Calibration so channel
    objects handle their own save/load/convert logic. Fixes several bugs in the
    stub classes: __init (missing __), save() referencing undefined variables,
    QuadraticCalibration.load() loading wrong keys, class name typo, and
    is_calibrated() returning True when calibration_date is None.
    [calibration.py]
2026-03-04 - Original version of the st7789 display driver. I will drop this as it does not work as well as the st7789-framebuffer class
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2026-03-07 Add ST7789 display support with BoardContext lazy-evaluation cache
    - display.py: ST7789 SPI display setup (76x284, rotation=1, pins 4-7,
    10-11), ezFBfont rendering with helvetica and fixed fonts,
    display_blank(), display_convertor_info(), display_error() with
    word-wrap using font and display metrics from live objects
    - board.py: BoardContext dict subclass with lazy ADC reads and
    calibrated conversion; override __getitem__ to call __missing__
    (MicroPython dict does not call __missing__ natively); clear and
    refresh display every 10 poll ticks; call display_blank() during setup
    - Fix bugs: iout_raw variable name, _do_breath_step() spelling,
    vout_cal->vout key, docstring placement,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
    [board.py, display.py, fluke45.py]
2026-03-07 Add EMA filtering to ADC readings; misc firmware updates
    - board.py: EMA filter on raw ADC readings updated every 20ms poll
    tick; BoardContext reads from _ema dict instead of BQ25758 directly;
    alpha=0.095 gives tau~200ms; first sample initialises without windup;
    fix __missing__ not called in MicroPython by overriding __getitem__;
    fix dict.get()->[] throughout; add class docstring warning
    - main.py, st7789_purefb.py, test_display.py, test_font.py,
    fluke45.py: misc updates
    [board.py, fluke45.py, main.py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]
2026-03-09 Add test equipment udev aliases and switch stress test
    - Update IT8511 port references to /dev/it8511 (udev alias by FTDI serial)
    - Add DEFAULT_PORT to fluke45.py for /dev/fluke45 (udev alias by USB path)
    - Document udev rules and LM74810 100nF cap fix in hardware/NOTES.md
    - Add test_switch_stress.py: 100-cycle on/off switch validation script
    (Board #2 switch 2 passed 100/100 at 10A load with clean V_on/V_off)
    [automated_calibration.py, do_fine_voltage_calibration.py, fluke45.py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]
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2026-03-09 Refactor BoardContext to plain class with get/set/clear methods
    Removes dict inheritance and __getitem__/__missing__ overrides that were
    needed to work around MicroPython's dict implementation.
2026-03-09 Add BQ25758 limit queries and setters to BoardContext
    Six new keys for get(): output_current_limit, output_voltage_limit,
    input_current_limit, input_voltage_limit, reverse_current_limit,
    reverse_voltage_limit. set() writes through to BQ25758 and invalidates
    the cache.
    [board.py]
2026-03-09 Add switch and BQ25758 limit keys to BoardContext; add load_startup()
    BoardContext.get() now supports switch0-3, switch_vsense0-3, and six
    BQ25758 limit keys. BoardContext.set() handles switch0-3 (non-zero=on)
    and the six settable BQ25758 limits.
    load_startup() reads startup.dat on boot, parsing name=value lines and
    applying them via context.set() to configure initial hardware state.
    Called from main.py after board.setup().
2026-03-11 Add RemoteRepl class and refactor test_switch_stress to use it
    remote_repl.py provides a clean raw-REPL client for MicroPython boards:
    - find_rp2350_port() discovers port by USB VID/PID (0x2E8A:0x0005)
    - Short serial timeout instead of in_waiting (avoids OSError on Linux/VMware)
    - Context manager support, stderr reporting, setup_board() helper
    test_switch_stress.py updated to use RemoteRepl, removing inline
    board_exec() and serial setup.
    [remote_repl.py, test_switch_stress.py]
2026-03-11 Refactor test_switch_stress: argparse, correct IT8500 remote control, 5A default
    - Switch to argparse for cleaner CLI (switch, cycles, --current, --v-on-min,
    --v-off-max, --load-port, --board-port)
    - Add control_set_remote() before configuring IT8511 (fixes silent 0xB0 error
    that prevented constant_current_set from taking effect)
    - Add control_set_local() on exit
    - Default load current changed from 1A to 5A
    [test_switch_stress.py]
2026-03-11 Add thermistor and RP2350 die temperature readings
    BQ25758: add get_ts_adc() (raw TS/VREGN fraction) and get_ts_celsius()
    using Steinhart-Hart coefficients fitted to Semitec 103AT datasheet data.
    Move math import to top of file.
    board.py: add get_die_temp() using RP2350 internal ADC channel 4.
    BoardContext: add die_temp, ts_celsius, ts_adc keys.
2026-03-11 Add bypass mode, current ADC calibration sweep and corrected IIN/IOUT scaling
    - BQ25758: add set_bypass_enable()/get_bypass_enable() for high-side FET bypass
    - BQ25758: correct IIN_ADC_SCALE to 0.8mA/LSB (measured; datasheet says 2mA/LSB)
    IOUT_ADC_SCALE confirmed at 2.0mA/LSB; both now give calibration gain ~1.0
    - BQ25758: move CURRENT_SCALE/VOLTAGE_SCALE to class constants with self. prefix
    - calibration.py: clamp calibrate_iout_adc/iin_adc to zero to avoid phantom
    current at no load from ADC floor offset correction
    - current_sweep.py: new script to sweep IT8511 in bypass mode, record IIN/IOUT
    ADC vs reference, fit linear calibration and upload to board in one pass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
    [BQ25758.py, calibration.py, current_sweep.py]
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2026-03-14 Calibration, BQ25758, display and driver improvements
    Calibration scripts:
    - Rename automated_calibration.py → vout_sweep.py for consistent naming
    - Add vin_sweep.py: VIN ADC sweep using OWON SPM6103 PSU, fits linear and
    quadratic, uploads quadratic calibration (2.7x better than linear)
    - Add owon.py: OWON SPM6103 PSU driver
    - current_sweep.py: update bypass method names (set_bypass/get_bypass)
    calibration.py:
    - Promote vin_adc from LinearCalibration to QuadraticCalibration
    - set_vin_calibration() now accepts quad_a/b/c parameters
    - Add zero-guard in LinearCalibration.convert() and QuadraticCalibration.convert()
    to prevent phantom readings when ADC returns 0
    BQ25758.py:
    - Rename set_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
    [BQ25758.py, board.py, calibration.py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]
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2026-03-18 Add discharge/reverse mode, watchdog config, and display arrow direction
    firmware/charger.py:
    - Add STATE_WAITING: polls for Vin and Vbat before enabling, replaces hard
    fault on missing battery/input at startup
    - Add STATE_DISCHARGE with start_discharge(context, v_output) method
    - FAULT auto-retries via WAITING after 30s
    - Vin loss during charging pauses to WAITING and resumes when restored
    - BQ25758 reconnect (watchdog/power loss) restarts charger via start()
    - Rename reverse_mode_input_*_limit context keys to reverse_voltage/current
    - Add v_discharge_cutoff and i_discharge to ChargingProfile
    - Add v_min_input to ChargingProfile; LIFEPO4_2S_5AH: 9V min input
    firmware/BQ25758.py:
    - Add ge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
    [BQ25758.py, board.py, charger.py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]
2026-03-20 Add UPS auto-reverse support and EN_AUTO_REV configuration
    - BQ25758: add get/set_auto_reverse() for EN_AUTO_REV (bit 1 REG0x19),
    auto-switches to reverse on VACUV trip; add get/set_hiz()
    - board: add software UPS monitor (_ups_check) triggered by VIN EMA;
    power restoration detected via switch_vsense0 (external side of ideal
    diode, independent of converter output in reverse mode)
    - board: ups_vin_threshold, ups_restore_threshold, ups_restore_delay
    all configurable via startup.dat
    - calibration: fix current calibration dead-band — allow negative
    reverse-mode currents through instead of clipping to 0
    - display: animated arrow reverses direction in reverse mode, hidden
    when conver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
    [BQ25758.py, board.py, calibration.py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]
2026-03-20 Refactor UPS recovery to use VIN vs reverse_voltage setpoint
    Remove software-triggered reverse enable (too slow — VACUV hardware path
    handles this). Replace switch_vsense0-based restoration detection with VIN
    comparison: since the converter cannot drive VIN above its own reverse_voltage
    setpoint, VIN > reverse_voltage × (1 + margin) unambiguously indicates
    external power has returned.
    Checked every 200ms alongside display refresh (no extra I2C overhead).
    Config via startup.dat: ups_restore_margin, ups_restore_delay.
    [board.py]
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2026-03-20 Exclude calibration_results/ from version control
    Calibration data is now stored per-board on the firmware filesystem.
    The calibration_results/ directory contains generated sweep CSVs, plots,
    and work-in-progress .dat files that don't need to be tracked.
    [board1_voltage_sweep_20260218.csv, board1_voltage_sweep_fine_20260218.csv, board2_voltage_sweep_fine_20260218.csv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]
2026-03-22 UPS auto-reverse improvements and scope capture tooling
    - Add get/set_forward_enable() for EN_CHG bit (REG0x17) — controls forward
    charging independently of CE pin for faster EN_AUTO_REV switchover
    - Add get/set_auto_reverse() context support (EN_AUTO_REV, REG0x19)
    - Document that EN_AUTO_REV bypasses CE pin; enabled=1 required alongside
    auto_reverse=1 for fast switchover and consistent is_enabled() state
    firmware/board.py:
    - Add forward_enable and auto_reverse to context get/set
    - _ups_recovery_check: use calibrated vin (not vin_raw) for threshold
    - _ups_recovery_check: restart charger on power restoration
    - set_charger: only clear reverse_enable in stop() when i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
    [BQ25758.py, board.py, charger.py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]
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2026-03-29 Fixed ordering of IT8511 connection messages
    [vin_sweep.py]
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
